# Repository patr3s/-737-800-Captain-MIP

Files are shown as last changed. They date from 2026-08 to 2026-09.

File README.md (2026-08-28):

# 737-800 Captain MIP

Modulárny 1:1 Captain-side Main Instrument Panel pre PMDG 737-800.

## Aktuálny stav

- DU bezel v2: referenčný rozmer 203,2 × 203,2 mm; aktívny otvor 169,7 × 169,7 mm.
- PFD+ND carrier v1: parametrický návrh, rozdelený na samostatný PFD a ND rám pre tlačovú plochu 260 × 260 mm.
- BenQ 18,5\" PETG cradle v1: `HOLD/DO NOT PRINT`; hlavné zaťaženie prevezme pevný oceľový VESA 100 držiak, tlačené budú iba nenosné dorazy a adaptéry.
- DU bezel v3: parametrická backlit-ready svetlá základňa, tmavá face vrstva a samostatný difúzor.
- Backlight test panel v1: technologický kupón s LED kanálom a presvietiteľnými znakmi.
- Dual-concentric knob v1: samostatné parametrické knoby; rozmery hriadeľov sú zatiaľ provisional.
- PFD/ND fascia v1: kompletná 445 × 266 mm predná maska rozdelená na tlačiteľné segmenty; čaká na CAL-003 fit-check.
- PFD/ND Pop Out alignment: fyzická 1:1 geometria prepočítaná na BenQ 1366 × 768.
- Elektronika: Arduino Mega 2560 + MobiFlight; WINCTRL MCP/EFIS.

## Štruktúra

- `CAD/` – parametrické zdrojové modely
- `Ready-to-Print/` – overené exporty určené pre 5s3a
- `Docs/` – technické poznámky, merania a montáž
- `BOM/` – zoznam dielov a stav obstarania
- `Photos/` – fotografie prototypov a montáže

## Pravidlo vydávania dielov

Súbor sa presunie do `Ready-to-Print/` až po kontrole rozmerov, úspešnom STL exporte a kontrole, že sa zmestí na 260 × 260 mm podložku. Experimentálne exporty zostávajú pri zdroji v `CAD/`.

## Najbližší mechanický krok

Dokončiť backlight test v1.1 a heat-set kalibráciu. Následne nasucho osadiť PFD/ND carrier a vybrať pevný oceľový VESA 100 držiak pre hlavné zaťaženie BenQ.

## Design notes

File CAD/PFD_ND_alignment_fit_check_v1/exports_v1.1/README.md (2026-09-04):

# CAL-003B exports

Corrective exports following the measured CAL-003 report:

- center fascia tongue stepped 4.8 mm below its feet,
- fascia seam joiner hole pitch corrected to 20 mm,
- multi-hole assembly clearance set to 3.4 mm.

The 3MF is an engineering assembly preview. Only the two STL files are print
outputs; printing instructions are in `Ready-to-Print`.

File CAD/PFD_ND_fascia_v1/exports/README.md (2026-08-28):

# PFD/ND fascia v1 – prototype exports

The folder contains base and dark-face exports for seven modular segments, optional 0,4 mm diffuser layers for the four top/bottom segments, and a rear M3 center-seam joiner.

These exports are not yet Ready-to-Print. Release depends on successful CAL-003 alignment/fit-check results.

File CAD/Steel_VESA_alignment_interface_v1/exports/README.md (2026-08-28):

# Steel VESA alignment interface v1 – PROVISIONAL

These printed parts do not carry monitor weight. The steel VESA bracket and structural MIP frame remain the primary support.

- XY plate: ±4 mm slot travel.
- Z shims: 0,5 / 1,0 / 2,0 mm.

Do not print until the exact steel VESA bracket and its frame mounting-hole pattern are selected.

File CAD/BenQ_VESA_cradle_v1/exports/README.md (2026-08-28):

# BenQ VESA cradle v1 – HOLD / DO NOT PRINT

Tieto PETG diely sa po technickej revíi nepoužijú ako hlavný dlhodobý nosník monitora. Primárne zaťaženie má niesť pevný oceľový VESA 100 × 100 mm držiak pripevnený ku konštrukcii MIP. Exporty zostávajú iba ako história návrhu.

Exporty sú geometricky skontrolované a všetky sa zmestia na Anycubic Kobra X 260 × 260 mm.

| Súbor | Počet | Rozmer dielu |
|---|---:|---:|
| `737-MIP-005_VESA-plate_v1.stl` | 1 | 170 × 170 × 7 mm |
| `737-MIP-005A_rear-wing_v1.stl` | 4 | 150 × 26 × 7 mm |
| `737-MIP-005B_depth-arm_v1.stl` | 4 | 78 × 26 × 7 mm |
| `737-MIP-005C_bottom-stabilizer_v1.stl` | 2 | 76 × 24 × 7 mm |

**Nevytlačiť ako výrobnú zostavu.**

Tlačové nastavenia a počty sú v `Docs/PRINT_BenQ_cradle_v1.md`.

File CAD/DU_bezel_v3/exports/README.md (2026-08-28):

# DU bezel v3 – exporty

| Súbor | Počet pre PFD+ND | Materiál | Stav |
|---|---:|---|---|
| `737-MIP-001_DU-bezel-light-base_v3.stl` | 2 | biely PETG | čaká na overenie servisného rastra |
| `737-MIP-001A_DU-bezel-dark-face_v3.stl` | 2 | čierny PETG | čaká na overenie servisného rastra |
| `737-MIP-001B_DU-bezel-diffuser_v3.stl` | 2 | natural/biely PETG, 0,4 mm | čaká na overenie servisného rastra |

Obrys je 203,2 × 203,2 mm a otvor 169,7 × 169,7 mm. Diely sa zmestia na Kobra X bez delenia. Zatiaľ ich nepresúvať do `Ready-to-Print`.

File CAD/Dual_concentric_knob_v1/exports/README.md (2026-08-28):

# Dual-concentric knob v1 – PROVISIONAL

Tieto STL sú iba tvarový prototyp. Neobjednávať ani netlačiť väčšiu sériu pred zmeraním konkrétneho dual-concentric enkódera.

- `737-MIP-KNB-001_lower-knob_PROVISIONAL_v1.stl`
- `737-MIP-KNB-002_upper-knob_PROVISIONAL_v1.stl`

Aktuálne bores 8,2 a 6,2 mm sú parametrické skúšobné hodnoty, nie potvrdené výrobné rozmery.

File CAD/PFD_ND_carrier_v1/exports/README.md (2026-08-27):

# Prototype exports – carrier v1

Tieto STL sú geometricky skontrolované, ale zatiaľ nie sú uvoľnené ako `Ready-to-Print`.

Pred tlačou oboch hlavných rámov treba potvrdiť, že montážne otvory fyzického alebo pôvodného DU bezel v2 majú raster 183,2 × 183,2 mm. Spojovacia lišta a horné rozhranie od tohto rastra nezávisia.

Exporty:

- `737-MIP-003_PFD-carrier_v1.stl` – ľavý PFD rám, 1 ks
- `737-MIP-004_ND-carrier_v1.stl` – pravý ND rám, 1 ks
- `737-MIP-003A_joiner-v1.stl` – nastaviteľná spojovacia lišta, 2 ks
- `737-MIP-003B_top-interface-v1.stl` – horná konzola rozhrania, 2 ks

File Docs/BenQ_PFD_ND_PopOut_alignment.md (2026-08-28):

# BenQ PFD/ND Pop Out Panel Manager alignment

## Physical source geometry

- Active LCD: 410 × 232 mm.
- BenQ resolution: 1366 × 768 px.
- PFD/ND physical opening: 169,7 × 169,7 mm.
- Center pitch: 209,8 mm.
- Visible gap: 40,1 mm.

Independent axis conversion is required because the physical pixel pitch is slightly different in X and Y:

- X: `410 / 1366 = 0,300146 mm/px`.
- Y: `232 / 768 = 0,302083 mm/px`.

## Recommended Pop Out values

The following values are relative to the top-left pixel of the BenQ desktop. If Windows places the BenQ at a non-zero desktop coordinate, add that monitor origin to `Left` and `Top`.

| Window | Left | Top | Width | Height |
|---|---:|---:|---:|---:|
| PFD | **51** | **103** | **565** | **562** |
| ND | **750** | **103** | **565** | **562** |

Unrounded calculations:

- PFD Left: 50,81 px.
- ND Left: 749,80 px.
- Top: 103,12 px.
- Width: 565,39 px.
- Height: 561,77 px.
- Pixel gap after rounding: 134 px.
- Left/right pixel margins after rounding: approximately 51 px.

These values intentionally follow the confirmed physical 1:1 geometry, not the current accidental 565 × 562 pop-out placement.

## Alignment procedure with the physical fascia

1. Configure Windows to use the BenQ at native 1366 × 768 resolution and 100 % scaling.
2. Disable overscan/scaling in the GPU and monitor menu; the desktop must fill the active LCD exactly.
3. Enter the values above for PFD and ND.
4. Install the monitor behind the fascia with the steel VESA bracket still slightly loose in X/Y.
5. Display a high-contrast calibration image or the PMDG PFD/ND pop-outs.
6. Mechanically center the active LCD behind both physical openings using the ±3 mm alignment allowance.
7. Tighten the steel bracket only after both openings show equal margins.
8. Fine-tune Pop Out values by 1–2 px only after mechanical alignment. Do not use large pixel corrections to compensate for a mechanically misplaced monitor.
9. Save the final measured values and monitor desktop origin in the project documentation.

If the physical Windows desktop is rotated, scaled, or the BenQ is not at 100 %, these coordinates must be recalculated.

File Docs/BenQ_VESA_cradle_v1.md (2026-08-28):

# BenQ VESA cradle v1 – HOLD / DO NOT PRINT

## Rozhodnutie po revízii 5s3a

Tlačený PETG cradle sa nebude používať ako hlavný dlhodobý nosný prvok. PETG sa pri trvalom statickom zaťažení môže časom dotvarovať. Hlavné zaťaženie monitora preto prevezme pevný oceľový VESA 100 × 100 mm držiak upevnený do konštrukčného rámu MIP.

Existujúce SCAD/STL zostávajú zachované ako vývojová referencia, ale majú stav `HOLD/DO NOT PRINT`. Nové tlačené diely budú iba nastaviteľné podložky, bočné dorazy a stabilizátory bez hlavnej nosnej funkcie. Tie sa navrhnú podľa geometrie vybraného oceľového držiaka a suchej montáže.

## Použité fyzické rozmery

| Parameter | Hodnota |
|---|---:|
| Monitor | 445 × 266 × 60 mm |
| Aktívna LCD plocha | 410 × 232 mm |
| Aktívna plocha odľava/zhora | 18 / 18 mm |
| VESA | 100 × 100 mm |
| Ľavá horná VESA diera odľava/zhora | približne 170 / 80 mm |

Aktuálny carrier používa medzeru 6,6 mm a celkovú šírku 445,0 mm. Bezely sú asymetricky posunuté tak, aby boli viditeľné otvory centrované na aktívnom LCD. Tento dokument ďalej opisuje pôvodný tlačený cradle iba ako archivovanú vývojovú koncepciu.

## Architektúra

- Centrálna VESA platňa 170 × 170 × 7 mm nesie hlavné zaťaženie monitora.
- Štyri zadné krídla prepájajú platňu s bočnými hĺbkovými ramenami.
- Štyri bočné ramená prenášajú zaťaženie do vonkajších okrajov PFD/ND carrieru.
- Dve spodné podpery s nastaviteľným M3 nylonovým alebo TPU dotykom iba tlmia pohyb. Nesmú nadvihovať monitor ani preberať hlavné zaťaženie.
- Monitor sa po odskrutkovaní štyroch VESA skrutiek vyberá zozadu; zadná zostava nezakrýva bočné oblasti konektorov.
- Žiadny samostatný tlačený diel neprekračuje 170 × 170 × 78 mm.

## Nastaviteľnosť

Všetky štyri VESA otvory majú zaoblený dvoj-osový obrys 10 × 10 mm s minimálnou šírkou 5,2 mm. Umožňujú približne ±2,4 mm korekciu v horizontálnom aj vertikálnom smere súčasne. Pri montáži sa použijú široké podložky, všetky skrutky sa najprv nechajú voľné a dotiahnu sa až po zarovnaní obrazu.

## Spojovací materiál

- Tlačené spoje: M3 skrutky, podložky a M3 heat-set vložky.
- VESA do monitora: 4× skrutka podľa skutočného závitu monitora, pravdepodobne M4. M3 skrutku nepoužívať len preto, že ostatné spoje sú M3.
- Maximálnu hĺbku zaskrutkovania do monitora treba overiť fyzicky. Skrutka sa nikdy nesmie dotiahnuť na doraz vo vnútri monitora.
- Odporúčané široké podložky pod všetky podlhovasté otvory.

## Prístup ku konektorom

Krídla sú umiestnené v zadnej stredovej rovine a bočné ramená mimo obrysu monitora. VGA a napájací konektor musia byť pri prvej suchej montáži overené so zapojenými káblami. Kábel potrebuje voľný polomer ohybu; ak konkrétny konektor koliduje, príslušné krídlo sa presunie v slote, nie kábel násilne ohne.

## Poradie montáže

1. Zmontovať PFD a ND carrier so stredovou medzerou 6,6 mm, zatiaľ bez monitora.
2. Osadiť bočné hĺbkové ramená, ale M3 skrutky nechať mierne povolené.
3. Pripojiť štyri zadné krídla k VESA platni.
4. Priložiť zostavu k monitoru a overiť závit aj bezpečnú dĺžku VESA skrutiek.
5. Zavesiť monitor cez VESA, zapojiť VGA aj napájanie a skontrolovať prístup.
6. Zarovnať aktívnu plochu za DU otvormi a postupne dotiahnuť VESA a M3 spoje.
7. Spodné stabilizátory nastaviť iba na ľahký dotyk s krytom monitora.

## Pred tlačou celej zostavy

- Vytlačiť M3 kalibračný diel a preniesť výsledný priemer heat-set kapsy do parametra `m3_insert`.
- Fyzicky overiť, že VESA závit je M4 a zistiť bezpečnú dĺžku skrutky.
- Overiť raster servisných otvorov DU bezel v2.
- Urobiť suchý CAD/ručný test polohy VGA a napájacieho konektora podľa fotografie zadnej strany.

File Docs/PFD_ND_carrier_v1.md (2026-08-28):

# PFD + ND carrier v1

## Účel

Carrier v1 je pevná, servisovateľná základňa pre dva samostatné DU bezely. Nie je to držiak monitora. BenQ bude mať vlastnú zadnú kolísku, doplnenú po fyzickom meraní.

Fyzické rozmery BenQ sú už zapracované. Nominálna stredová medzera medzi carrier rámami je **6,6 mm**, takže zostava má šírku presne **445,0 mm**. Bezely sú v carrier rámoch asymetricky posunuté smerom k stredu: ľavý +8,5 mm a pravý −7,5 mm. Tým je fyzická medzera bezelov tiež 6,6 mm a viditeľné otvory sú centrované na aktívnom LCD.

## Konštrukcia

- Dva samostatné rámy PFD a ND, každý 219,2 × 219,2 × 5 mm.
- Každý hlavný diel sa zmestí na tlačovú plochu 260 × 260 mm.
- Otvor rámu je 170,7 × 170,7 mm (169,7 mm aktívny otvor + 1,0 mm montážna vôľa).
- Bezel sa upevňuje štyrmi M3 skrutkami; nominálny servisný raster je 183,2 × 183,2 mm.
- Dve samostatné spojovacie lišty so slotmi ponechávajú rozstup PFD/ND nastaviteľný.
- Horné sloty tvoria rozhranie pre budúci nosník EFIS/MCP.
- ND rám má na pravom okraji tri sloty pre napojenie center MIP.
- Vonkajšie okraje majú dvojicu slotov pre bočné hĺbkové ramená BenQ cradle.

## Dôležitá otvorená položka

Raster 183,2 × 183,2 mm bol rekonštruovaný z deklarovaných servisných bodov bezel v2 (10 mm od okrajov). Pred tlačou celej zostavy treba porovnať zdrojový alebo fyzický bezel v2. Ak sa líši, upraví sa parameter `bezel_hole_edge`.

## Odporúčaná skúšobná tlač

- Materiál: PETG pre finálny nosný diel; PLA je vhodné na rozmerový prototyp.
- Vrstva: 0,20 mm.
- Steny: 4.
- Horné/spodné vrstvy: 5.
- Výplň: 20–25 % gyroid.
- Orientácia: naplocho, zadnou stranou na podložke.
- Podpery: bez podpier.
- Kompenzácia elephant foot: podľa kalibrácie tlačiarne.

## Spojovací materiál pre carrier

- 8× M3 skrutka pre bezely (dĺžka podľa reálnej hĺbky vložky).
- 4× M3 skrutka + 4× matica alebo heat-set vložka pre dve spojovacie lišty.
- 4× M3 skrutka pre dve horné konzoly rozhrania.
- 3× M3 skrutka pre pravé rozhranie na center MIP.

## Stav verifikácie

- [x] Parametrický zdroj vytvorený.
- [x] Maximálny obrys hlavného dielu pod 260 × 260 mm.
- [x] STL exportovaný; OpenSCAD CGAL kontrola: `Simple: yes`.
- [x] Obrysy exportov skontrolované: 219,2 × 219,2 × 5 mm (PFD/ND), 92 × 18 × 5 mm (spojka), 80 × 22 × 5 mm (horné rozhranie).
- [ ] Overený raster otvorov proti bezel v2.
- [ ] Skúšobne vytlačené.
- [ ] Rozstup PFD/ND uzamknutý po fyzickom CAL-003 fit-check teste.
- [x] Nominálna medzera rámov nastavená na 6,6 mm podľa 445 mm obrysu monitora.

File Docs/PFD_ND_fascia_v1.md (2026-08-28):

# PFD/ND fascia v1

## Purpose

The fascia covers the full 445 × 266 mm monitor envelope and masks every LCD area outside the two confirmed 169,7 mm DU openings. Two 203,2 mm bezel assemblies install into 203,6 mm fascia cutouts, providing 0,2 mm nominal clearance per edge.

## Printable segmentation

The fascia is divided into seven base/face segments:

- top-left and top-right rails,
- bottom-left and bottom-right rails,
- left outer rail,
- center rail,
- right outer rail.

Top and bottom center seams use rear 70 × 16 × 3 mm M3 joiner plates. The narrow center rail is captured by the two bezels and the top/bottom rails; it is a mask, not a primary structural member. Carrier frames behind the fascia provide the main printed-module stiffness.

No fascia segment exceeds 222,5 × 203,6 mm, so every part fits the 260 × 260 mm Kobra X bed.

## Layer philosophy

- Light base: 3,2 mm white/light PETG.
- Dark face: 1,0 mm black PETG.
- Optional diffuser under future illuminated top/bottom legends: 0,4 mm white/natural PETG.
- Rear cable routes are reserved for a separate panel-dimmer circuit.
- The DU bezel v3 carries its own 5,6 × 2,0 mm channel for 5 mm COB lighting.

No unverified Boeing legend positions are engraved in v1. The screenshot is used only as a visual reference; future legends remain parameterized until reliable 1:1 dimensions are available.

## Service

The fascia and bezels are removed from the front with M3 screws. The monitor remains independently supported by the future fixed steel VESA bracket and is removed from the rear. Fascia/carrier parts only establish alignment and light stabilization; they do not carry monitor weight.

## Release status

CAD/STL are prototype exports. They remain outside `Ready-to-Print` until the center alignment fit-check confirms:

- 6,6 mm physical bezel gap,
- carrier-to-bezel offset,
- fascia cutout clearance,
- center mask fit,
- M3 seam registration.

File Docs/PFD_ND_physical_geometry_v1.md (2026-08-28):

# PFD + ND physical geometry v1

## Confirmed inputs

- BenQ body: 445 × 266 × 60 mm.
- Active LCD: 410 × 232 mm.
- Active LCD offset: 18 mm left and 18 mm top; derived right border is 17 mm and bottom border 16 mm.
- DU visible opening: 169,7 × 169,7 mm.
- DU bezel: 203,2 × 203,2 mm.

## Final nominal arrangement

The carrier pair is 445,0 mm wide: `219,2 + 6,6 + 219,2`. The physical bezel gap is also 6,6 mm because each bezel is shifted toward the center of its asymmetric carrier. The complete visible pair is centered on the active LCD, not on the monitor plastic.

| Quantity | Value |
|---|---:|
| Physical bezel gap | 6,6 mm |
| PFD-center to ND-center pitch | 209,8 mm |
| Gap between visible DU openings | 40,1 mm |
| Total visible pair width | 379,5 mm |
| Active LCD margin left/right | 15,25 / 15,25 mm |
| Active LCD margin top/bottom | 31,15 / 31,15 mm |

Coordinates below use the active LCD top-left as `(0,0)`:

| Opening | Left | Top | Width | Height | Center X | Center Y |
|---|---:|---:|---:|---:|---:|---:|
| PFD | 15,25 | 31,15 | 169,7 | 169,7 | 100,10 | 116,00 |
| ND | 225,05 | 31,15 | 169,7 | 169,7 | 309,90 | 116,00 |

Coordinates relative to the complete 445 × 266 mm monitor body:

| Opening | Left | Top | Center X | Center Y |
|---|---:|---:|---:|---:|
| PFD | 33,25 | 49,15 | 118,10 | 134,00 |
| ND | 243,05 | 49,15 | 327,90 | 134,00 |

The physical bezel outer edges are at X 16,5–219,7 mm and 226,3–429,5 mm. This leaves 16,5 mm at the monitor left and 15,5 mm at the right, matching the 0,5 mm active-area offset relative to the monitor-body center.

## Change from the previous carrier

The previous 7 mm carrier gap with centered bezels produced a physical bezel gap of approximately 23 mm because each 219,2 mm carrier added an 8 mm inner margin. In v1 final geometry:

- carrier gap changes from 7,0 to 6,6 mm,
- the left bezel shifts +8,5 mm toward the center,
- the right bezel shifts −7,5 mm toward the center,
- physical bezel gap becomes 6,6 mm,
- visible opening gap becomes 40,1 mm.

The 6,6 mm physical gap is a project interface derived from confirmed monitor and bezel dimensions. It remains parameterized and should be verified with the low-cost center fit-check before large prints.

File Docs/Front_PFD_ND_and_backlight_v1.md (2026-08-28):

# Viditeľná PFD/ND časť a backlight v1

## Rozmerová politika

Referenčný PMDG screenshot sa používa iba na identifikáciu vizuálneho usporiadania a typov ovládačov. Rozmery odvodené iba z pixelov sa nepoužívajú ako výrobné rozmery.

Potvrdené rozmery DU sú 203,2 × 203,2 mm a otvor 169,7 × 169,7 mm. Nový bezel v3 používa rovnaký nominálny servisný raster 183,2 × 183,2 mm ako carrier v1. Raster treba pred veľkou tlačou overiť vytlačením rohového fit-check dielu alebo fyzickým meraním.

## DU bezel v3

Bezel je rozdelený na:

- svetlú nosnú základňu 3,2 mm,
- tmavú prednú vrstvu 1,2 mm,
- samostatný 0,4 mm difúzny prstenec,
- spredu otvorený LED kanál široký 5,6 mm a hlboký 2,0 mm pre 5 mm COB pásik,
- štyri alternatívne vývody kabeláže,
- štyri servisné M3 otvory.

Rovnaký model sa použije pre PFD aj ND. Čierna predná vrstva sa môže tlačiť priamo alebo nastriekať; svetlá základňa a difúzor majú zostať svetlé/priesvitné v miestach presvietenia.

## Dual-concentric ovládače

Červeným označené ovládače na referencii sú dvojité koncentrické prvky. Panelový otvor aj oba knob kryty sú parametrické. Aktuálne skúšobné hodnoty 10,2 mm panelový otvor, 8,2 mm spodný shaft a 6,2 mm horný shaft sú **provisional** a nesmú sa použiť ako finálny fit bez zmerania konkrétneho enkódera.

Knoby sú oddelené diely:

- spodný knob: 28 × 10 mm,
- horný knob: 17 × 14 mm,
- radiálny pilot pre M3 zaisťovaciu skrutku.

## Backlight testovací panel

Opravená revízia 1.1 panelu 120 × 62 mm testuje:

- dvojmateriálovú skladbu svetlá základňa/tmavá maska,
- presvietiteľné texty a symbol,
- 0,4 mm difúzor medzi LED a čiernou face vrstvou,
- 2,0 mm spredu otvorený LED kanál a bočný vývod,
- otvor pre budúci dual-concentric encoder,
- servisné M3 upevnenie.

Použiť dva rovné približne 90 mm úseky 12 V bieleho COB pásika širokého 5 mm. Čierna face vrstva používa stencil písmo, takže stredy písmen nie sú samostatné neprintovateľné ostrovčeky. Samostatný dimmer okruh má používať vlastné dva vodiče a spoločný bod napájania až v elektronickej rozvodnici.

## V1 výnimky

- Analógový flap indicator môže zostať nefunkčný placeholder alebo byť vynechaný.
- Zeleno označený manuálny ukazovateľ sa do v1 nezahŕňa.

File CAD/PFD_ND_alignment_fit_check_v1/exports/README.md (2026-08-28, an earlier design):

# PFD/ND alignment fit-check v1

Geometrically identical verified STL files are released in `Ready-to-Print/PFD-ND-Alignment-Fit-Check-v1` with print and measurement instructions.

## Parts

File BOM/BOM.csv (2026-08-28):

Category | Item | Specification | Quantity | Status | Notes
Electronics | Arduino Mega 2560 | Rev3 | 1 | ordered | MobiFlight controller
Controls | Rotary encoder | EC11 with D-shaft and push switch | 5 | ordered | Prototype stock
Controls | Toggle switch | MTS-103 3-position 3-pin | 5 | ordered | Prototype stock
Avionics | WINCTRL MCP/EFIS | 737NG compatible | 1 | set | Upper interface reserved
Display | BenQ monitor | 18.5 inch 445x266x60 mm VESA 100x100 | 1 | measured | Active area 410x232 offset 18x18 mm
Hardware | Heat-set insert | M3 for printed plastic | TBD | to purchase | Confirm outer diameter before pocket freeze
Hardware | Screw | M3 assorted lengths | TBD | to purchase | Final lengths after stack-up test
Printed | PFD carrier frame | v1 PETG | 1 | design | 219.2 x 219.2 x 5 mm
Printed | ND carrier frame | v1 PETG | 1 | design | 219.2 x 219.2 x 5 mm
Printed | Carrier joiner bar | v1 PETG | 2 | design | Slotted adjustment
Printed | Upper EFIS/MCP interface | v1 PETG | 2 | design | One provisional bracket per DU
Printed | M3 calibration coupon | v1 PETG | 1 | ready to print | Print before carrier frames
Printed | BenQ VESA center plate | v1 PETG | 1 | HOLD DO NOT PRINT | Superseded as primary support due to PETG creep
Printed | BenQ rear wing | v1 PETG | 4 | HOLD DO NOT PRINT | Superseded by steel VESA support concept
Printed | BenQ side depth arm | v1 PETG | 4 | HOLD DO NOT PRINT | Superseded by steel VESA support concept
Printed | BenQ bottom stabilizer | v1 PETG | 2 | redesign pending | May return as non-load-bearing alignment stop
Hardware | Fixed steel VESA bracket | 100x100 mm low-profile | 1 | to select | Primary monitor support attached to MIP structure
Printed | DU bezel light base | v3 light or white PETG | 2 | design | Backlit-ready; verify 183.2 mm service-hole pitch
Printed | DU bezel dark face | v3 black PETG | 2 | design | Visible PFD and ND face layer
Printed | DU bezel diffuser ring | v3 natural or white PETG | 2 | design | 0.4 mm backlight diffuser
Printed | Backlight test base | v1 white PETG | 1 | ready to print | Technology coupon only
Printed | Backlight test dark face | v1 black PETG | 1 | ready to print | Technology coupon only
Printed | Backlight test diffuser | v1.1 natural or white PETG 0.4 mm | 1 | ready to print | Technology coupon only
Printed | Dual concentric lower knob | v1 black PETG | TBD | provisional | Requires encoder shaft measurement
Printed | Dual concentric upper knob | v1 black PETG | TBD | provisional | Requires encoder shaft measurement
Printed | PFD/ND fascia light base segments | v1 white PETG | 7 | prototype | Release after CAL-003 fit-check
Printed | PFD/ND fascia dark face segments | v1 black PETG | 7 | prototype | Release after CAL-003 fit-check
Printed | PFD/ND fascia diffuser segments | v1 natural or white PETG 0.4 mm | 4 | prototype | Top/bottom rails only
Printed | PFD/ND fascia center seam joiner | v1 PETG | 2 | prototype | M3 rear joiner for top and bottom seams
Printed | PFD/ND alignment fit-check | CAL-003 PETG | 1 set | ready to print | 9 small parts; no heat-set inserts required
Printed | Steel VESA XY alignment plate | v1 PETG | TBD | provisional | Non-load-bearing; exact steel bracket pending
Printed | Steel VESA Z shim set | 0.5/1.0/2.0 mm PETG | TBD | provisional | Non-load-bearing depth adjustment

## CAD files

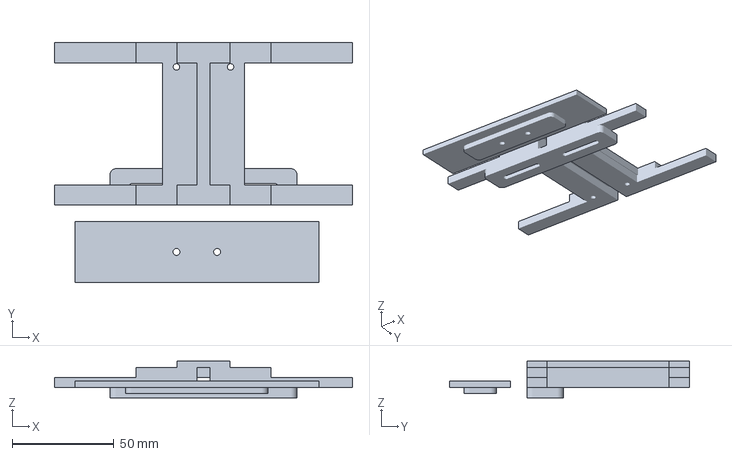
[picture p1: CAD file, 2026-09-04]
CAD/PFD_ND_alignment_fit_check_v1/exports_v1.1/737-MIP-CAL-003B_assembly-preview_v1.1.3mf
146.6 x 118.0 x 18.0 mm

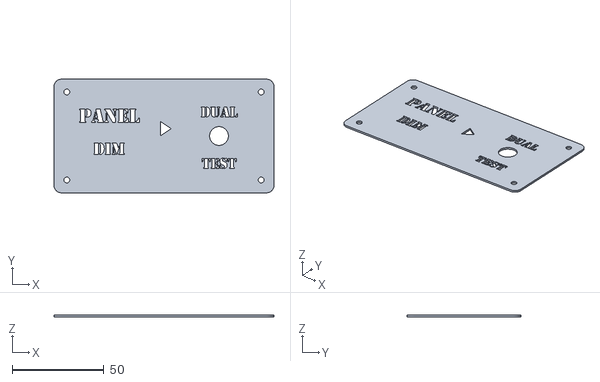
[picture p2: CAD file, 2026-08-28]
CAD/Backlight_test_panel_v1/exports/737-MIP-CAL-002A_backlight-face_v1.1.stl
120.0 x 62.0 x 1.00

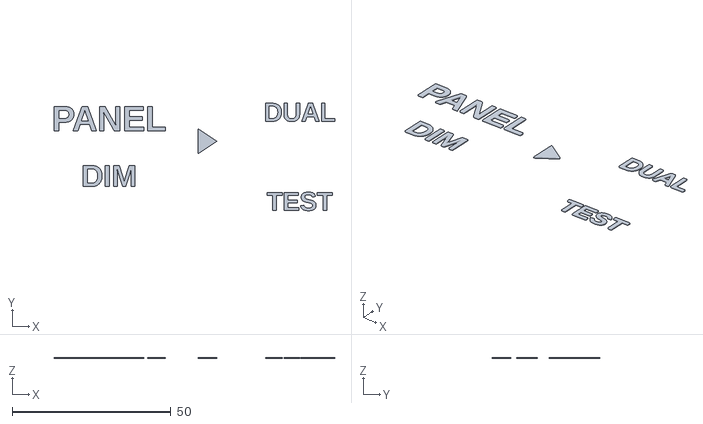
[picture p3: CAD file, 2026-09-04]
CAD/Backlight_test_panel_v1/exports_multicolor_v1/737-MIP-CAL-004_legends-B-0.4mm.stl
88.4 x 33.9 x 0.4

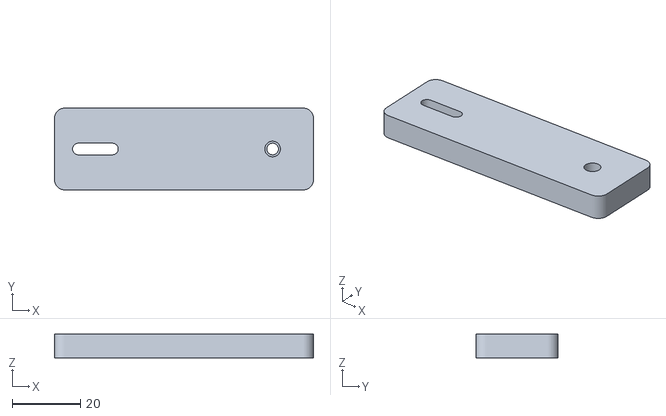
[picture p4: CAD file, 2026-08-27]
CAD/BenQ_VESA_cradle_v1/exports/737-MIP-005C_bottom-stabilizer_v1.stl
76.0 x 24.0 x 7.00

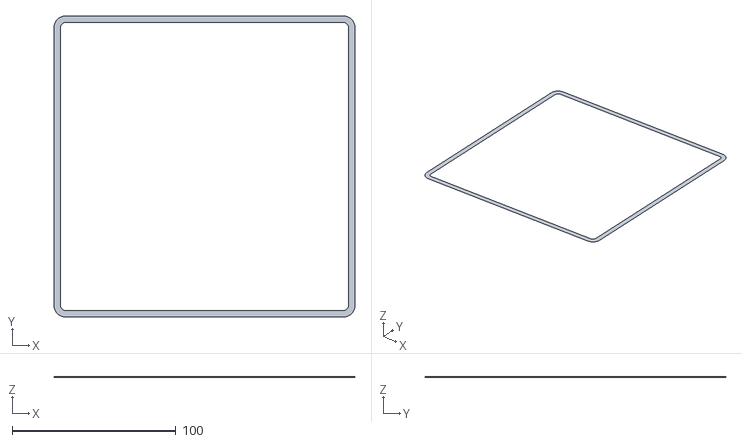
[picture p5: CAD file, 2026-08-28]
CAD/DU_bezel_v3/exports/737-MIP-001B_DU-bezel-diffuser_v3.stl
183.7 x 183.7 x 0.4

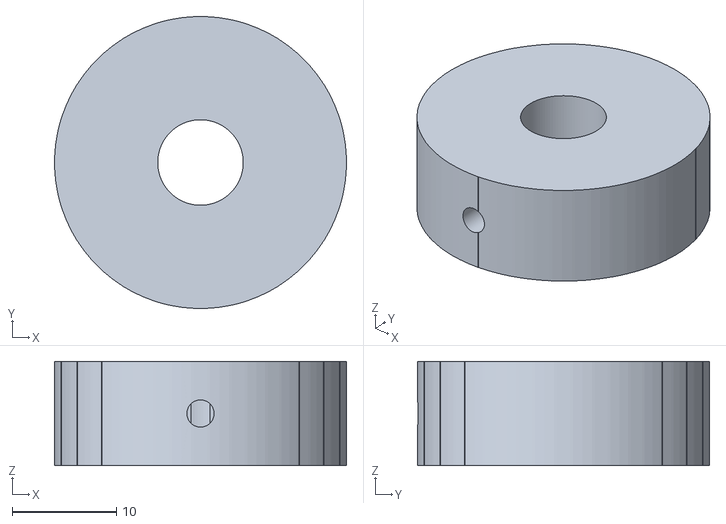
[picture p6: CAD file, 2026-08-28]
CAD/Dual_concentric_knob_v1/exports/737-MIP-KNB-001_lower-knob_PROVISIONAL_v1.stl
28.0 x 28.0 x 10.0

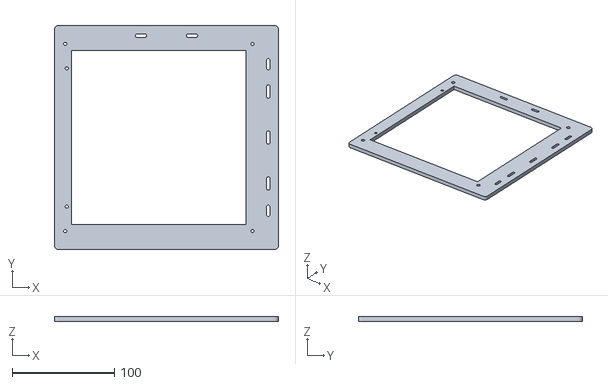
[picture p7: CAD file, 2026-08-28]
CAD/PFD_ND_carrier_v1/exports/737-MIP-004_ND-carrier_v1.stl
219.2 x 219.2 x 5.00

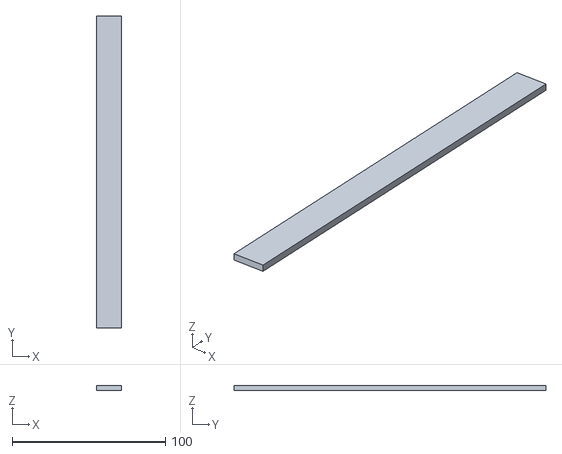
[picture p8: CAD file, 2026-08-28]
CAD/PFD_ND_fascia_v1/exports/737-MIP-006_left_rail_base_v1.stl
16.3 x 203.6 x 3.20

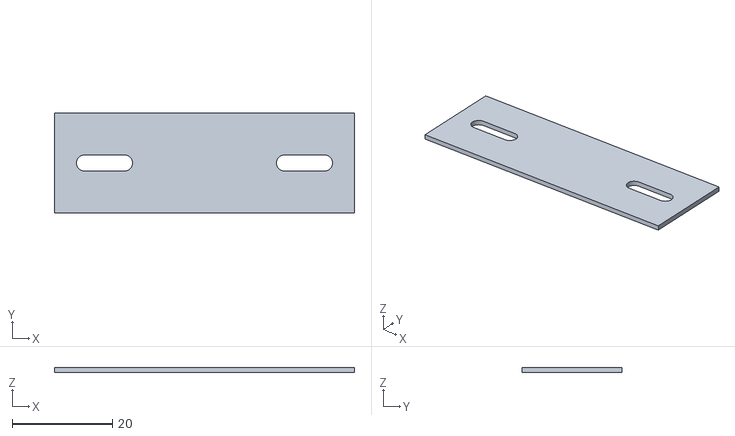
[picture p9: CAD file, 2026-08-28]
CAD/Steel_VESA_alignment_interface_v1/exports/737-MIP-007_shim_10_PROVISIONAL_v1.stl
60.0 x 20.0 x 1.00

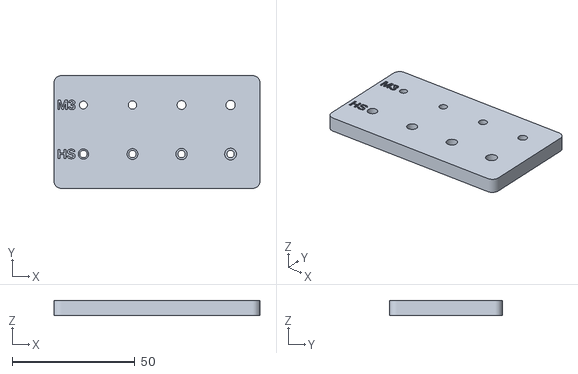
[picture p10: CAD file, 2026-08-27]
Ready-to-Print/737-MIP-CAL-001_M3-calibration-coupon_v1.stl
84.0 x 46.0 x 6.00

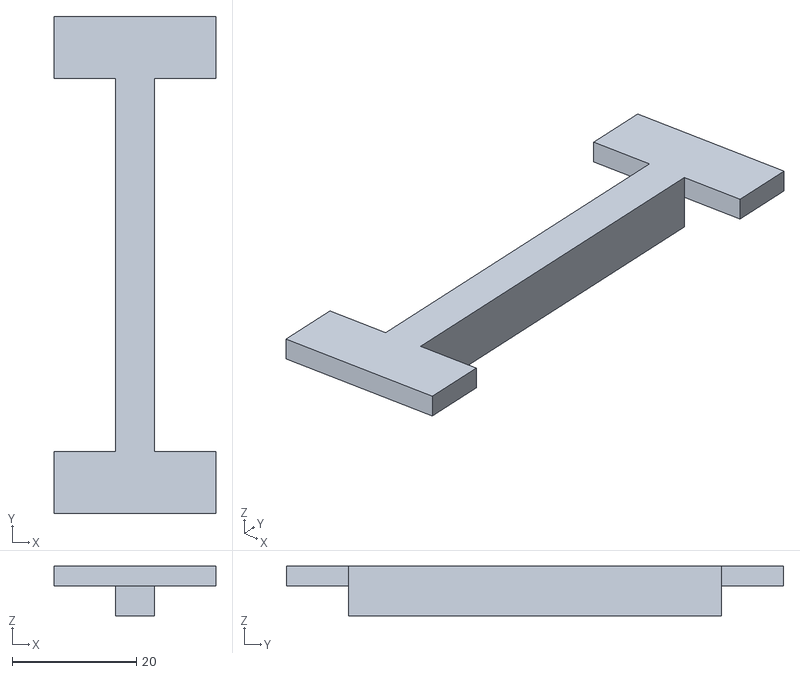
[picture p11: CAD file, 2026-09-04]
Ready-to-Print/PFD-ND-Alignment-Correction-CAL-003B/737-MIP-CAL-003B_fascia-center_v1.1.stl
26.0 x 80.0 x 8.00

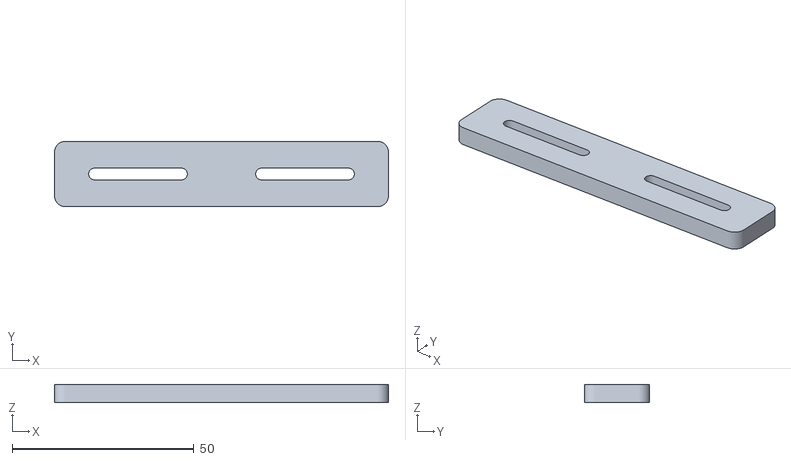
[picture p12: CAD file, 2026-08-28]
Ready-to-Print/PFD-ND-Alignment-Fit-Check-v1/737-MIP-CAL-003_carrier_joiner_v1.stl
92.0 x 18.0 x 5.00

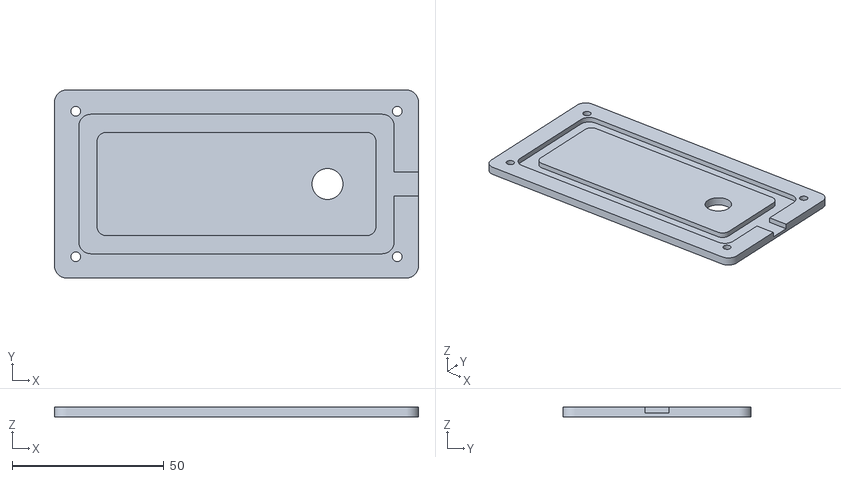
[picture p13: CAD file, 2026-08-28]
CAD/Backlight_test_panel_v1/exports/737-MIP-CAL-002_backlight-base_v1.1.stl
120.0 x 62.0 x 3.20

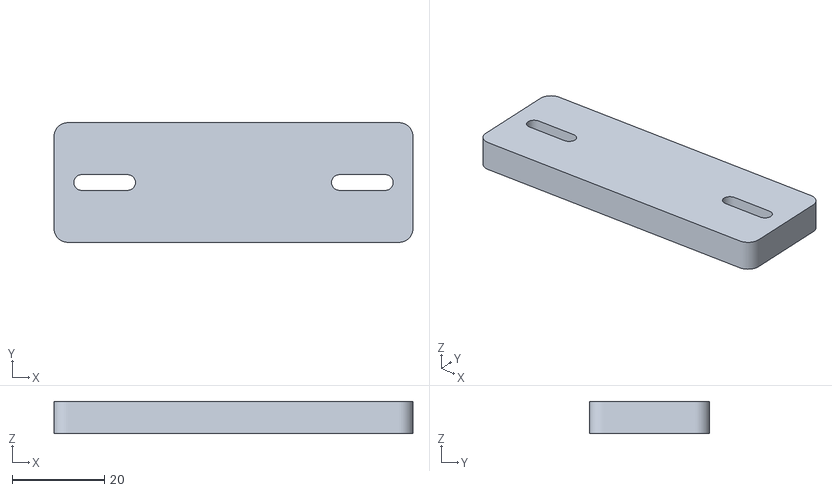
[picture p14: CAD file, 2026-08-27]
CAD/BenQ_VESA_cradle_v1/exports/737-MIP-005B_depth-arm_v1.stl
78.0 x 26.0 x 7.00

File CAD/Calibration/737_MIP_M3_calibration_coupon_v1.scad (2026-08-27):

/*
  737-800 Captain MIP – M3 print calibration coupon v1
  Units: mm

  Row A: heat-set insert pockets 4.2 / 4.4 / 4.6 / 4.8 mm
  Row B: M3 clearance holes 3.2 / 3.4 / 3.6 / 3.8 mm
*/

$fn = 64;

coupon_x = 84;
coupon_y = 46;
coupon_z = 6;
corner_r = 3;
test_x = [12, 32, 52, 72];
heatset_d = [4.2, 4.4, 4.6, 4.8];
clearance_d = [3.2, 3.4, 3.6, 3.8];
heatset_depth = 4.2;
pilot_d = 3.0;

module rounded_plate() {
    hull() {
        for (x = [corner_r, coupon_x-corner_r])
            for (y = [corner_r, coupon_y-corner_r])
                translate([x,y,0]) cylinder(h=coupon_z, r=corner_r);
    }
}

module engraved_label(label, x, y) {
    translate([x, y, coupon_z-0.5])
        linear_extrude(0.6)
            text(label, size=4, halign="center", valign="center",
                 font="Liberation Sans:style=Bold");
}

difference() {
    rounded_plate();

    // Heat-set pockets with a smaller pilot hole continuing through the base.
    for (i = [0:3]) {
        translate([test_x[i], 14, coupon_z-heatset_depth])
            cylinder(h=heatset_depth+0.1, d=heatset_d[i]);
        translate([test_x[i], 14, -0.1])
            cylinder(h=coupon_z-heatset_depth+0.2, d=pilot_d);
    }

    // Through-holes for checking printed M3 running clearance.
    for (i = [0:3])
        translate([test_x[i], 34, -0.1])
            cylinder(h=coupon_z+0.2, d=clearance_d[i]);

    // Recessed row markers.
    engraved_label("HS", 5, 14);
    engraved_label("M3", 5, 34);
}

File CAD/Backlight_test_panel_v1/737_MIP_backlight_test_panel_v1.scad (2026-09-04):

/*
  Backlight multicolor A/B technology coupon, CAL-004
  Tests: light base, multicolor dark face + translucent legends, LED cavity,
  rear service access and dual-concentric encoder panel opening.
*/

$fn = 64;
part = "assembly";

panel_w = 120;
panel_h = 62;
corner_r = 4;
base_t = 3.2;
face_t = 1.0;
legend_b_t = 0.4; // empirically verified by 5s3a: 2 layers at 0.20 mm
encoder_hole = 10.2; // provisional until the selected encoder is measured
m3_clearance = 3.2; // calibrated on Anycubic Kobra X, Anycubic PETG, flow 0.96
led_channel_depth = 2.0;

module rounded_rect_2d(size,r) {
    hull()
        for(x=[r,size[0]-r]) for(y=[r,size[1]-r])
            translate([x,y]) circle(r=r);
}

module mounting_holes(h) {
    for(x=[7,panel_w-7]) for(y=[7,panel_h-7])
        translate([x,y,-0.1]) cylinder(h=h+0.2,d=m3_clearance);
}

module labels_2d() {
    // Normal bold font: counters are retained by the separately printed legends.
    translate([30,42]) text("PANEL",size=8,halign="center",valign="center",
                            font="Liberation Sans:style=Bold");
    translate([30,24]) text("DIM",size=7,halign="center",valign="center",
                            font="Liberation Sans:style=Bold");
    translate([90,44]) text("DUAL",size=6,halign="center",valign="center",
                            font="Liberation Sans:style=Bold");
    translate([90,16]) text("TEST",size=6,halign="center",valign="center",
                            font="Liberation Sans:style=Bold");
    translate([58,31]) polygon(points=[[0,0],[6,4],[0,8]]);
}

module light_base() {
    difference() {
        linear_extrude(base_t) rounded_rect_2d([panel_w,panel_h],corner_r);
        mounting_holes(base_t);
        translate([90,31,-0.1]) cylinder(h=base_t+0.2,d=encoder_hole);

        // Front-open light cavity. Two straight 5 mm COB strips sit on its
        // long edges; the multicolor white legends provide final diffusion.
        translate([8,8,base_t-led_channel_depth])
            linear_extrude(led_channel_depth+0.1)
                difference() {
                    rounded_rect_2d([104,46],4);
                    // Retain a support boss around the provisional encoder.
                    translate([82,23]) circle(d=18);
                }
        translate([108,27,base_t-led_channel_depth])
            cube([12,8,led_channel_depth+0.1]);
    }
}

module face_black() {
    difference() {
        linear_extrude(face_t) rounded_rect_2d([panel_w,panel_h],corner_r);
        mounting_holes(face_t);
        translate([90,31,-0.1]) cylinder(h=face_t+0.2,d=encoder_hole);
        linear_extrude(face_t+0.2) labels_2d();
    }
}

module face_legends(h) {
    linear_extrude(h) labels_2d();
}

module assembly_preview() {
    color("ivory") light_base();
    color([0.12,0.12,0.12]) translate([0,0,base_t]) face_black();
    color([1,0.8,0.25,0.9]) translate([0,0,base_t]) face_legends(legend_b_t);
}

if(part=="base") light_base();
else if(part=="face_black") face_black();
else if(part=="legends_a") face_legends(face_t);
else if(part=="legends_b") face_legends(legend_b_t);
else assembly_preview();

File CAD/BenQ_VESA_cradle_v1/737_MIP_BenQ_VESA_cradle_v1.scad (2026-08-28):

/*
  737-800 Captain MIP – BenQ 18.5 inch VESA cradle v1
  Units: mm

  Measured monitor:
    body 445 x 266 x 60
    active area 410 x 232, offset 18 left / 18 top
    VESA 100 x 100
    top-left VESA hole approx. 170 left / 80 top

  Printed joints use M3 + heat-set inserts. The four screws entering the
  monitor must match its native VESA thread (normally M4; verify physically).
*/

$fn = 48;
part = "assembly";

monitor_w = 445;
monitor_h = 266;
monitor_d = 60;
active_w = 410;
active_h = 232;
active_left = 18;
active_top = 18;

carrier_w = 445.4;
carrier_h = 219.2;
carrier_t = 5;
monitor_x = (carrier_w-monitor_w)/2;
monitor_y = 6.25; // aligns active top with the DU opening datum
monitor_front_z = 9;

vesa_pitch = 100;
vesa_tl_x = 170;
vesa_tl_y = 80;
vesa_center_x = monitor_x + vesa_tl_x + vesa_pitch/2;
vesa_center_y = monitor_y + vesa_tl_y + vesa_pitch/2;
vesa_plane_z = monitor_front_z + monitor_d;

plate_w = 170;
plate_h = 170;
plate_t = 7;
plate_corner = 5;
vesa_slot_len = 10; // ±2.4 mm around a 5.2 mm M4 clearance width
vesa_clearance = 5.2;

m3_clearance = 3.2; // calibrated by 5s3a; printed cradle remains on HOLD
m3_insert = 4.6;
m3_slot_len = 10;

wing_len = 150;
wing_w = 26;
wing_t = 7;
depth_arm_len = 78;
depth_arm_w = 26;
depth_arm_t = 7;
side_offset = 12;

stabilizer_len = 76;
stabilizer_w = 24;
stabilizer_t = 7;
pad_hole_d = 3.4;

module rounded_plate(size, r=3) {
    hull() {
        for (x = [r, size[0]-r])
            for (y = [r, size[1]-r])
                translate([x,y,0]) cylinder(h=size[2], r=r);
    }
}

module slot_x(length, diameter, height) {
    hull() {
        translate([-length/2,0,0]) cylinder(h=height,d=diameter);
        translate([ length/2,0,0]) cylinder(h=height,d=diameter);
    }
}

module slot_y(length, diameter, height) {
    rotate([0,0,90]) slot_x(length,diameter,height);
}

module adjust_hole_2d(travel, diameter, height) {
    delta = (travel-diameter)/2;
    hull()
        for (x=[-delta,delta]) for (y=[-delta,delta])
            translate([x,y,0]) cylinder(h=height,d=diameter);
}

module vesa_plate() {
    difference() {
        rounded_plate([plate_w,plate_h,plate_t],plate_corner);

        // Rounded-square openings compensate the approximate C and D
        // dimensions simultaneously (about +/-2.4 mm in both axes).
        for (sx=[-1,1]) for (sy=[-1,1])
            translate([plate_w/2+sx*vesa_pitch/2,
                       plate_h/2+sy*vesa_pitch/2,-0.1])
                adjust_hole_2d(vesa_slot_len,vesa_clearance,plate_t+0.2);

        // M3 wing interfaces: two per side, slotted vertically.
        for (x=[10,plate_w-10]) for (y=[32,plate_h-32])
            translate([x,y,-0.1]) slot_y(m3_slot_len,m3_clearance,plate_t+0.2);

        // Cable/service opening and weight reduction.
        translate([plate_w/2-29,plate_h/2-29,-0.1])
            rounded_plate([58,58,plate_t+0.2],6);
    }
}

module rear_wing() {
    difference() {
        rounded_plate([wing_len,wing_w,wing_t],3);
        for (x=[12,wing_len-12])
            translate([x,wing_w/2,-0.1])
                slot_x(m3_slot_len,m3_clearance,wing_t+0.2);
    }
}

module depth_arm() {
    // Printed flat. Two holes attach to carrier/rear wing with M3 fasteners.
    difference() {
        rounded_plate([depth_arm_len,depth_arm_w,depth_arm_t],3);
        for (x=[11,depth_arm_len-11])
            translate([x,depth_arm_w/2,-0.1])
                slot_x(m3_slot_len,m3_clearance,depth_arm_t+0.2);
    }
}

module bottom_stabilizer() {
    // Carries no main load. An M3 nylon-tip screw or TPU pad lightly contacts
    // the monitor casing and prevents fore/aft vibration.
    difference() {
        rounded_plate([stabilizer_len,stabilizer_w,stabilizer_t],3);
        translate([12,stabilizer_w/2,-0.1])
            slot_x(m3_slot_len,m3_clearance,stabilizer_t+0.2);
        translate([stabilizer_len-12,stabilizer_w/2,-0.1])
            cylinder(h=stabilizer_t+0.2,d=pad_hole_d);
        translate([stabilizer_len-12,stabilizer_w/2,stabilizer_t-4.2])
            cylinder(h=4.3,d=m3_insert);
    }
}

module assembly_preview() {
    // Monitor envelope (transparent); connector side remains unobstructed.
    color([0.12,0.12,0.12,0.45])
        translate([monitor_x,monitor_y,monitor_front_z])
            cube([monitor_w,monitor_h,monitor_d]);

    // Central VESA plate behind monitor.
    color("orange")
        translate([vesa_center_x-plate_w/2,vesa_center_y-plate_h/2,vesa_plane_z])
            vesa_plate();

    // Four rear wings. They terminate outside the monitor sides and attach to
    // the depth arms; all are separate printable pieces.
    for (y=[vesa_center_y-50,vesa_center_y+50]) {
        color("goldenrod")
            translate([-side_offset,y-wing_w/2,vesa_plane_z]) rear_wing();
        color("goldenrod")
            translate([carrier_w+side_offset-wing_len,y-wing_w/2,vesa_plane_z]) rear_wing();
    }

    // Side depth arms shown upright, clear of the monitor side walls.
    for (x=[-side_offset,carrier_w+side_offset-depth_arm_w])
        for (y=[38,carrier_h-38])
            color("steelblue")
                translate([x,y-depth_arm_w/2,0])
                    rotate([0,-90,0]) depth_arm();

    // Two lower stabilizers; contact force is adjusted with M3 screws/pads.
    for (x=[28,carrier_w-28-stabilizer_w])
        color("darkorange")
            translate([x,carrier_h+36,monitor_front_z])
                rotate([0,90,0]) bottom_stabilizer();
}

if (part=="vesa_plate") vesa_plate();
else if (part=="rear_wing") rear_wing();
else if (part=="depth_arm") depth_arm();
else if (part=="bottom_stabilizer") bottom_stabilizer();
else assembly_preview();

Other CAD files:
Ready-to-Print/Backlight-Multicolor-AB-CAL-004/737-MIP-CAL-004_face-black.stl
CAD/Backlight_test_panel_v1/exports_multicolor_v1/737-MIP-CAL-004_backlight-base.stl
CAD/DU_bezel_v3/exports/737-MIP-001_DU-bezel-light-base_v3.stl
CAD/DU_bezel_v3/737_MIP_DU_bezel_v3.scad
CAD/Backlight_test_panel_v1/exports/737-MIP-CAL-002B_backlight-diffuser_v1.1.stl
CAD/Backlight_test_panel_v1/exports_multicolor_v1/737-MIP-CAL-004_face-black.stl
CAD/Backlight_test_panel_v1/exports_multicolor_v1/737-MIP-CAL-004_legends-A-1.0mm.stl
CAD/Backlight_test_panel_v1/obsolete_v1/737-MIP-CAL-002A_backlight-face_v1.stl
CAD/Backlight_test_panel_v1/obsolete_v1/737-MIP-CAL-002B_backlight-diffuser_v1.stl
CAD/Backlight_test_panel_v1/obsolete_v1/737-MIP-CAL-002_backlight-base_v1.stl
CAD/BenQ_VESA_cradle_v1/exports/737-MIP-005A_rear-wing_v1.stl
CAD/BenQ_VESA_cradle_v1/exports/737-MIP-005_VESA-plate_v1.stl
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

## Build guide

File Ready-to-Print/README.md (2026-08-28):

# Ready-to-Print

Tento priečinok obsahuje iba skontrolované výrobné exporty pre 5s3a.

Carrier v1 sem bude presunutý po úspešnom STL exporte, kontrole geometrie a potvrdení rastra montážnych otvorov voči DU bezel v2.

## Uvoľnené diely

- `737-MIP-CAL-001_M3-calibration-coupon_v1.stl` – vytlačiť 1 ks ako prvý diel projektu.
- `POKYNY_PRE_5s3a.md` – kompletné nastavenie tlače a postup vyhodnotenia testu.
- `Backlight-Test-v1/` – prvý trojvrstvový test podsvietenia; 3 STL a samostatný tlačový návod.
- `VYSLEDOK_5s3a.md` – výsledok CAL-001; M3 priechodzí otvor 3,2 mm potvrdený pre sivý Anycubic PETG, flow 0,96.
- `PFD-ND-Alignment-Fit-Check-v1/` – CAL-003, deväť malých dielov na overenie carrier/bezel/fascia geometrie a medzery pred veľkou tlačou.

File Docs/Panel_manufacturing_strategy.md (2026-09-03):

# Stratégia výroby panelov

Rozhodnuté 2026-09-03 (5s3a + patr3s). Týka sa všetkých predných panelov
s popismi a nosnej konštrukcie MIP.

## Rozhodnutia

1. **Skriňa, rámy a konzoly** sa vyrobia CNC frézovaním z **Forexu** a nalakujú.
2. **Predné panely s popismi sa tlačia**, nekupujú a nerobia z akrylátu.
3. **Popisy sa robia multicolor**, nie prierezom cez čiernu dosku.
4. **Zostávame pri parametrickom OpenSCAD zdrojáku**, cudzie STL nekupujeme.

---

## 1. Delenie výroby

| Časť | Technológia | Prečo |
|---|---|---|
| Skriňa MIP, rámy, konzoly, prepážky | Forex CNC + lak | Tabuľa 2 × 3 m, veľký diel vyjde v jednom kuse bez škár |
| Svetlotesné škatule za panelmi | tlač | 3D geometria, priehradky medzi popismi, kanály na LED |
| **Predné panely s popismi** | **tlač, multicolor** | viď sekcia 2 |
| Bezely, puzdrá gombíkov, držiaky encoderov | tlač | hĺbka, závity, dosadacie plochy |

### Prečo Forex nejde na predné panely

Forex je uzavretobunková PVC pena — nepriehľadná, svetlo v nej zaniká.
Vyfrézovaný popis s LED za ním nesvieti. Forex ide **len na nepodsvietené
konštrukčné diely**.

### Pozor pri Forexe

Je mäkký. Skrutka v ňom nedrží, heat-set vložka sa neuchytí, hrana sa dá
zatlačiť nechtom. Všade, kde ide o moment (gombík, encoder) alebo kde sa
bude panel často odoberať, treba **tlačenú alebo hliníkovú podložnú dosku
so závitom**. Neskrutkovať priamo do Forexu.

---

## 2. Multicolor popisy namiesto stencil fontu

### Problém so súčasným riešením

Stencil font v `labels_2d()` bol núdzový obchvat okolo voľných ostrovčekov
vo `dark_face()`. Pri jednom testovacom kupóne to prejde, pri celom kokpite nie:

- reálne 737 panely stencil font nemajú, majú čistý gotický
- stencilové písmo bude na každom paneli a bude to vidieť
- obmedzuje to výber fontu na celý projekt

### Riešenie

5s3a má **ACE Pro so štyrmi cievkami**. Popisy sa vytlačia ako **samostatná
farba v tej istej vrstve**, nie ako prierez.

Z jedného `.scad` sa exportujú dva STL so zdieľaným počiatkom:

| Export | Obsah |
|---|---|
| `*-face-black.stl` | doska mínus objem písma |
| `*-face-legends.stl` | len objem písma |

V sliceri sa načítajú ako **jeden objekt s časťami** a priradí sa filament
na časť.

### Zmena v CAD

Súčasný stav — písmo rezané cez celú hrúbku:

```scad
module dark_face() {
    difference() {
        linear_extrude(face_t) rounded_rect_2d([panel_w,panel_h],corner_r);
        mounting_holes(face_t);
        translate([90,31,-0.1]) cylinder(h=face_t+0.2,d=encoder_hole);
        linear_extrude(face_t+0.2) labels_2d();   // <- necháva ostrovčeky
    }
}
```

Navrhovaná zmena — rovnaký `difference()`, ale pribudne modul na samotné písmo
a `labels_2d()` sa vráti na normálny font:

```scad
module face_legends() {
    linear_extrude(legend_t) labels_2d();
}
```

plus nová vetva v `part` prepínači na export.

### Čo sa tým získa

| | Prierez + stencil | Multicolor |
|---|---|---|
| Voľné ostrovčeky | nutný stencil font | **žiadne**, všetko je spojené |
| Typografia | obmedzená na stencil | **akýkoľvek font** |
| Difúzia | cez otvor, ostrá hrana | cez biely plast, mäkká |
| Počet vrstiev | base + difúzor + face | **base + face** |

Samostatný difúzor tým odpadá — biele písmená sú samy difúzorom. Menej dielov,
menej skrutiek, tenší panel.

---

## 3. Hrúbka bieleho písmena — dve varianty na otestovanie

5s3a empiricky overil, že **na difúziu je optimum 0,4 mm bielej PETG**
(2 vrstvy pri 0,20 mm). Pri hrubšej vrstve svetlo výrazne ubúda.

Písmeno cez celú hrúbku face vrstvy by malo 1,2 mm, teda **3× viac než optimum**.
Preto treba porovnať dve varianty:

### Varianta A — písmeno cez celú hrúbku

`legend_t = face_t`. Jednoduchšie, jeden objem. Riziko: tmavšie popisy.

### Varianta B — písmeno 0,4 mm vpredu, zvyšok otvorený

`legend_t = 0.4`, za ním zostáva 0,8 mm otvorená dutina v čiernej doske.

Tlačí sa **lícom na podložku**: prvé dve vrstvy sú biele písmo + čierne okolie,
ďalšie vrstvy už len čierne s otvorom nad písmom. Žiadne mostíky, žiadne
podpery. Tá 0,8 mm dutina navyše svetlo trochu usmerní.

**Návrh:** vytlačiť obe varianty na `Backlight_test_panel_v1` a porovnať.
Kupón na to existuje a momentálne je aj tak blokovaný — týmto sa z neho stane
užitočný A/B test namiesto opravy stencil fontu.

---

## 4. Overiť pred rozbehnutím celého MIP

**Šírka ťahu písma proti priemeru trysky.**

`CLAUDE.md` má pravidlo ≥ 0,6 mm na embosované písmo. Boeing panelové popisy
majú výšku písmen ~3–4 mm a ťahy okolo 0,5 mm — pri 0,4 mm tryske je to
jedna extrúzia, teda na hrane použiteľnosti.

Zmerať najtenší ťah v reálnej veľkosti na jednom paneli. Ak vyjde pod 0,6 mm,
sú dve možnosti:

- **0,2 mm tryska** na predné panely
- písmo mierne zväčšiť

Lepšie to zistiť teraz než po desiatich vytlačených paneloch.

---

## 5. Prečo nekupujeme cudzie súbory

Zvažovali sme kúpiť hotové panely od 737DIYSIM. Zamietnuté, lebo predávajú
prevažne STL a my potrebujeme do geometrie zasahovať:

- font sa v STL nezmení
- na multicolor sa STL nerozdelí — treba dva objemy z jedného modelu
- nepasuje to na našu Forexovú skriňu, ktorú si robíme vlastnú
- `m3_clearance` na našich 3,2 mm sa neprenastaví

Parametrický OpenSCAD zdroják tieto štyri veci umožňuje, STL nie.

**Napriek tomu stojí za to kúpiť jeden ich panel ako rozmerovú referenciu.**
Za pár eur je odladená geometria — rozteče otvorov, veľkosti výrezov pre
encodery, proporcie popisov. Netlačiť, len premerať proti nášmu návrhu.
Najlacnejší spôsob, ako overiť, či naše čísla sedia na reálny 737.

Ak by predávali aj STEP alebo zdrojáky, oplatí sa to prehodnotiť — vtedy sa
to dá upraviť. Overiť v popise produktu, čo je v balíku.

---

## Nadväzujúce úlohy

| # | Úloha | Kto |
|---|---|---|
| 1 | Prekresliť `dark_face()` na dva exporty, zahodiť stencil font | patr3s |
| 2 | Pripraviť varianty A a B hrúbky písmena na backlight kupón | patr3s |
| 3 | Vytlačiť a porovnať A/B, vybrať `legend_t` | 5s3a |
| 4 | Zmerať najtenší ťah písma proti 0,4 mm tryske | 5s3a |
| 5 | Kúpiť jeden referenčný panel na premeranie | — |

Úloha 1 zároveň ruší blokujúcu chybu s voľnými ostrovčekmi
z `Ready-to-Print/VYSLEDOK_5s3a.md`, sekcia 3.1.

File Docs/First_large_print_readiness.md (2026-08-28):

# Pripravenosť pred prvou väčšou tlačou

## Môže sa tlačiť hneď

- M3 kalibračný diel: 1 ks, už v `Ready-to-Print`.
- Backlight test panel v1: základňa 1 ks, tmavá face vrstva 1 ks, difúzor 1 ks. Je to technologický test, nie finálny rozmerový panel.
- PFD/ND CAL-003 alignment fit-check: 1 sada deviatich malých dielov, bez heat-set vložiek.

## STL sú pripravené, ale ešte sa nemajú tlačiť ako finálne

- PFD carrier a ND carrier: čakajú na M3/heat-set kalibráciu a overenie rastra DU bezelu.
- DU bezel v3: čaká na overenie rastra štyroch servisných otvorov proti carrieru.
- BenQ PETG VESA cradle: `HOLD/DO NOT PRINT`; nahradí ho pevný oceľový VESA 100 nosník a nenosné tlačené dorazy.
- Dual-concentric knob set: čaká na presné rozmery hriadeľov enkódera.
- Kompletná fascia v1: CAD/STL hotové, čaká na výsledok CAL-003.

## Predbežný spojovací materiál pre celý PFD+ND modul

| Použitie | Predbežný počet |
|---|---:|
| M3 skrutky pre dva bezely | 8 |
| M3 skrutky pre dve stredové spojky | 4 |
| M3 skrutky pre dve horné konzoly | 4 |
| M3 skrutky pre bočné ramená a zadné krídla | 16 |
| M3 skrutky pre spodné stabilizátory | 4 |
| M3 rezerva | minimálne 12 |
| **M3 spolu** | **48 ks odporúčané minimum** |
| VESA skrutky do monitora | 4 ks, pravdepodobne M4 – overiť závit a dĺžku |

Odporúča sa sada M3 × 6/8/10/12/16/20 mm, široké M3 podložky a najmenej 20 M3 matíc. Presné dĺžky sa vyberú pri suchej montáži.

## Heat-set vložky

Predbežne treba približne 24–32 kusov M3 plus rezervu. Nekupovať náhodný rozmer: vybrať jeden konkrétny typ a oznámiť jeho vonkajší priemer a dĺžku. Kalibračný model sa pred tlačou upraví na jeho skutočnú dĺžku.

## Čo ešte zmerať alebo overiť

Na monitore už netreba opakovať celkové rozmery ani aktívnu plochu. Zostáva:

1. potvrdiť závit všetkých štyroch VESA otvorov,
2. zistiť maximálnu bezpečnú hĺbku zaskrutkovania,
3. odfotiť zadnú stranu so zapojeným VGA a napájacím káblom,
4. zmerať, koľko priestoru potrebuje každý konektor a ohyb kábla,
5. overiť, či zadný kryt nemá výstupok hrubší než uvedených 60 mm.

Pre dual-concentric panel treba neskôr zmerať priemer závitového puzdra enkódera, dĺžku a priemer oboch hriadeľov, tvar hriadeľov a vzdialenosť matice od prednej plochy panelu.

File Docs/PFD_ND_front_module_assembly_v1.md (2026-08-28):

# Complete PFD/ND front module assembly v1

## Front-to-rear stack

1. Dark fascia face segments, 1,0 mm.
2. Optional 0,4 mm fascia diffuser segments under future legends.
3. Light fascia base segments, 3,2 mm.
4. Two DU bezel v3 stacks installed in the fascia cutouts.
5. PFD and ND carrier frames behind the fascia.
6. BenQ front active plane aligned to the two carrier/bezel openings.
7. Fixed steel VESA 100 × 100 mm bracket attached to the structural MIP frame.

The steel bracket carries the monitor. Printed carrier/fascia parts establish XY alignment and light side contact only.

## Assembly datums

- Monitor-body top-left is `(0,0)`.
- PFD center: `(118,1; 134,0)` mm.
- ND center: `(327,9; 134,0)` mm.
- Carrier Y origin: 24,4 mm.
- Left carrier X origin: 0 mm.
- Right carrier X origin: 225,8 mm.
- Left bezel origin: `(16,5; 32,4)` mm.
- Right bezel origin: `(226,3; 32,4)` mm.

## Service sequence

1. Remove the front M3 bezel screws.
2. Remove bezel stacks and fascia segments as required.
3. Disconnect the independent COB/dimmer harness through the service connectors.
4. From the rear, disconnect VGA and power.
5. Support the monitor, loosen the steel VESA bracket and remove the monitor rearward.

Printed parts must never be used as the sole monitor support.

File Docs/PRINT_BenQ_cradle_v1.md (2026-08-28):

# Tlačové pokyny – ARCHÍV / NEPOUŽÍVAŤ

Tlačený PETG cradle má stav `HOLD/DO NOT PRINT`. Hlavné zaťaženie monitora bude niesť pevný oceľový VESA 100 × 100 mm držiak. Nasledujúce údaje zostávajú iba ako archív pôvodného návrhu.

## Materiál

Použiť PETG. Prednostne čierny PETG; biely PETG je funkčne rovnocenný a diely možno po odmastení, jemnom prebrúsení a základe na plasty nastriekať. Všetky nosné diely jednej zostavy sa odporúča tlačiť z rovnakej značky a šarže materiálu.

## Nastavenie

- Tryska 0,4 mm.
- Vrstva 0,20 mm.
- 5 stien/perimetrov.
- 6 horných a 6 spodných vrstiev.
- 30 % gyroid pre VESA platňu, krídla a hĺbkové ramená.
- 25 % gyroid pre spodné stabilizátory.
- Bez podpier; všetky výrobné STL sú orientované naplocho.
- Mierka 100 %, bez automatického zväčšovania otvorov slicerom.
- Teploty podľa overeného profilu konkrétneho PETG.

## Počty dielov

| Diel | Počet |
|---|---:|
| VESA plate | 1 |
| Rear wing | 4 |
| Depth arm | 4 |
| Bottom stabilizer | 2 |
| PFD carrier | 1 |
| ND carrier | 1 |
| Stredová spojka carrieru | 2 |
| Horná konzola EFIS/MCP | 2 |

## Kontrola po tlači

1. Diely musia ležať rovno bez zdvihnutých rohov.
2. M3 skrutka musí prejsť zvolenými priechodzími otvormi rukou.
3. Heat-set vložky osadiť kolmo podľa výsledku kalibračného dielu.
4. VESA platňa nesmie byť prehnutá; skontrolovať pravítkom cez obe diagonály.
5. Všetky drážky začistiť iba od voľných vlákien, nezväčšovať ich vrtákom pred skúšobnou montážou.
6. Prvú montáž robiť bez monitora, potom s monitorom a voľne založenými skrutkami.

## Povrchová úprava

Funkčné styčné plochy, heat-set kapsy, závity a dosadacie plochy podložiek sa nestriekajú. Pred farbením sa zamaskujú. Lakovať až po úspešnej suchej montáži celej zostavy.

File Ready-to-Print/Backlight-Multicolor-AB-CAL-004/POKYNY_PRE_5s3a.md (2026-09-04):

# CAL-004 – multicolor A/B backlight test

Cieľom je rozhodnúť, či biele PETG legendy môžu zároveň fungovať ako difúzor,
bez samostatnej difúznej dosky. Test neoveruje finálny Boeing font ani finálny
layout; tie zostávajú `PROVISIONAL`.

## Súbory a dva multicolor objekty

Základňu vytlačiť raz z bieleho alebo svetlého PETG:

- `737-MIP-CAL-004_backlight-base.stl`

V sliceri vytvoriť dva samostatné multicolor objekty. STL každej dvojice
načítať ako časti jedného objektu; všetky majú spoločný počiatok a mierku.

### Variant A – biela legenda cez celú hrúbku 1,0 mm

- čierna časť: `737-MIP-CAL-004_face-black.stl`
- biela časť: `737-MIP-CAL-004_legends-A-1.0mm.stl`

### Variant B – biela legenda iba 0,4 mm na prednej strane

- čierna časť: `737-MIP-CAL-004_face-black.stl`
- biela časť: `737-MIP-CAL-004_legends-B-0.4mm.stl`

Varianty tlačiť lícom na podložku. Pri variante B sú prvé dve vrstvy biele
legendy a čierne okolie; nad legendami zostáva 0,6 mm otvor v čiernej vrstve.

## Profil

- Anycubic PETG: čierny + biely, bez striekania.
- Tryska 0,4 mm, vrstva presne 0,20 mm.
- Mierka 100 %, bez podpier.
- 4 steny; face objekty 100 % výplň, základňa 25 % gyroid.
- Pre overený Anycubic PETG: 230 °C tryska, 75 °C podložka, flow 0,96.
- Skontrolovať purge tower a dostatočné prečistenie po zmene čierna/biela.

## Svetlo a zostavenie

Do predného kanála základne vložiť dva rovné približne 90 mm úseky bieleho
12 V COB LED pásika širokého 5 mm. Pásik nepripájať na Arduino pin. Použiť
12 V zdroj aspoň 0,5 A. Face variant položiť priamo na základňu a dočasne
uchytiť štyrmi M3 skrutkami, podložkami a maticami.

## Čo porovnať

- čitateľnosť vypnutého panelu za denného svetla,
- jas a rovnomernosť popisov v tme aj pri izbovom svetle,
- presvitanie čiernej plochy a svetelné lemy,
- viditeľnosť vrstiev alebo bodov LED,
- čistotu písmen a symbolu po multicolor tlači,
- najtenší reálne vytlačený ťah písma.

Výsledok zapísať osobitne pre A a B a priložiť fotografie s rovnakým
nastavením expozície. Samostatný difúzor sa z finálneho návrhu odstráni až
vtedy, keď jeden variant týmto testom prejde.

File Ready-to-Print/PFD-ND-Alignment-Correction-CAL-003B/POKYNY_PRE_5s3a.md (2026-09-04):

# CAL-003B – oprava stredovej fascie a seam spojky

Toto je lacná opravná tlač po meraní CAL-003. Pôvodné diely, ktoré už 5s3a
vytlačil, sa použijú znova. Netreba opakovať všetkých deväť dielov.

## Vytlačiť

- 1× `737-MIP-CAL-003B_fascia-center_v1.1.stl`
- 1× `737-MIP-CAL-003B_fascia-seam-joiner_v1.1.stl`

Materiál môže byť ľubovoľný dostupný PETG; farba pri tomto mechanickom teste
nie je dôležitá. Použiť rovnaký profil ako CAL-003: tryska 0,4 mm, vrstva
0,20 mm, 4 steny, 5 horných/spodných vrstiev, 25 % gyroid, bez podpier,
mierka 100 %, 230 °C / 75 °C a flow 0,96 pre rovnaký Anycubic PETG.

## Overenie

1. Nový stredový diel vložiť medzi pôvodné bezel kupóny. Spodný jazyk musí
   vojsť do medzery a obe krajné nohy musia súčasne dosadnúť na horné plochy
   bezelov bez kolízie. Jazyk má odskok 4,8 mm.
2. Skontrolovať vôľu jazyka: nominálne 0,20 mm na každej strane.
3. Novou seam spojkou spojiť pôvodné `fascia_seam_left/right`. Obe skrutky
   musia prejsť naraz; ich rozteč je opravená na 20 mm.
4. Použiť M3 skrutky s podložkami a maticami. Montážne otvory majú 3,4 mm,
   aby sa pri viacotvorovom spoji nesčítavali výrobné odchýlky.
5. Zapísať, či diely sadli bez úpravy, a odfotiť zostavu spredu aj zboku.

Ak oba body sedia, CAL-003B je prijatý a rovnaké opravy možno preniesť do
veľkej fascie. Kritické rozmery 6,60 mm a 39,99 mm už potvrdil CAL-003.

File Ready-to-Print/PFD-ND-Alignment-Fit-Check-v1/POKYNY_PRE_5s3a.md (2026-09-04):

# PFD/ND alignment fit-check v1

> **SUPERSEDED / DO NOT REPRINT:** CAL-003 was measured successfully, but two
> parts contain assembly errors. Use `PFD-ND-Alignment-Correction-CAL-003B`
> for the corrected center tongue and seam joiner.

## Purpose

This inexpensive coupon verifies the final center geometry before printing the complete 445 mm module:

- 6,6 mm physical carrier/bezel gap,
- 40,1 mm visible-opening gap,
- carrier opening edge,
- bezel stack edge,
- fascia center mask,
- M3 carrier joiner and fascia seam joiner.

No heat-set inserts are required. Use ordinary M3 through-screws, washers and nuts.

## Print quantities

Print one of every STL in this folder except this instruction file: 9 small parts total.

## Material and profile

- PETG, preferably the same Anycubic PETG/profile used for CAL-001.
- 0,4 mm nozzle, 0,20 mm layer.
- 4 walls, 5 top/bottom layers, 25 % gyroid.
- No supports, 100 % scale.
- Use the verified profile: 230 °C nozzle, 75 °C bed, flow 0,96, if the same grey Anycubic PETG is used.

## Assembly and measurement

1. Join `carrier_left` and `carrier_right` from behind with `carrier_joiner`; set the clear gap to exactly 6,6 mm before tightening.
2. Fit the two bezel coupons on the front carrier edges with M3 screws/nuts.
3. Insert the narrow fascia-center coupon between the bezel edges. It must enter without force and must not visibly rattle.
4. Measure the physical bezel-edge gap: target 6,6 mm.
5. Measure the two represented visible-opening edges: target 40,1 mm.
6. Assemble `fascia_seam_left` and `fascia_seam_right` with the rear seam joiner. The front faces must remain flush.
7. Photograph the assembly from the front, rear and side and record actual dimensions.

## Acceptance

- Carrier gap: 6,6 mm ±0,2 mm.
- Visible opening gap: 40,1 mm ±0,3 mm.
- Front fascia seam step: maximum 0,2 mm.
- M3 screws pass by hand through the 3,2 mm holes.
- No cracking or forced fit.

Do not print the complete fascia/carrier until this coupon is accepted.

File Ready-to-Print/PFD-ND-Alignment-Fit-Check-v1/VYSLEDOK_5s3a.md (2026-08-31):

# Výsledok CAL-003 – PFD/ND alignment fit-check v1

Tlačil a meral: 5s3a, 2026-08-31. Anycubic Kobra X, tryska 0,4 mm.

## Verdikt

**Všetky akceptačné kritériá splnené.** Geometria stredu je potvrdená, veľký
445 mm modul môže ísť ďalej.

Zároveň sú v CAD **tri chyby**, ktoré znemožnili fyzicky vykonať dva kroky
montáže. Kritériá sa dali overiť meraním, ale diely v tejto podobe nesadnú.

| Kritérium | Cieľ | Namerané | |
|---|---|---|---|
| Medzera medzi bezelmi | 6,6 ±0,2 | **6,60** | OK |
| Viditeľný otvor | 40,1 ±0,3 | **39,99** | OK |
| Stupeň v prednom spoji fascie | max 0,2 | **0,01** | OK |
| M3 skrutky cez otvory 3,2 | rukou | tesnejšie, viď nižšie | pozn. |
| Praskliny, násilné lícovanie | žiadne | žiadne | OK |

## Nastavenie tlače

Podľa pokynov, na overenom profile z CAL-001:

| Položka | Hodnota |
|---|---|
| Filament | Anycubic PETG, sivý |
| Tryska / podložka | 230 °C / 75 °C |
| Flow | 0,96 |
| Vrstva | 0,20 mm |
| Steny | 4 |
| Horné/spodné vrstvy | 5 |
| Výplň | 25 % gyroid |
| Podpery | žiadne, 100 % mierka |

Všetkých 9 dielov na jednu podložku, súčet plôch 24 456 mm² z 260 × 260 mm.

## A. Jednotlivé diely

| Diel | Rozmer | Nominál | Namerané |
|---|---|---|---|
| carrier_left | šírka × výška | 70,00 × 80,00 | 70,02 × 80,00 |
| carrier_left | hrúbka | 5,00 | 5,03 |
| carrier_left | vnútorná lišta | 16,25 | 16,23 |
| carrier_right | šírka × výška | 70,00 × 80,00 | 70,02 × 79,98 |
| carrier_right | hrúbka | 5,00 | 5,00 |
| carrier_right | vnútorná lišta | 16,25 | 16,32 |
| bezel_left | šírka × výška | 30,00 × 80,00 | 30,09 × 80,00 |
| bezel_left | hrúbka | 4,80 | 4,79 |
| bezel_left | vnútorná lišta | 16,75 | 16,84 |
| bezel_right | šírka × výška | 30,00 × 80,00 | 30,04 × 79,96 |
| bezel_right | hrúbka | 4,80 | 4,77 |
| bezel_right | vnútorná lišta | 16,75 | 16,79 |
| fascia_center | šírka jazyka | 6,20 | **6,20** |
| fascia_center | celková šírka | 26,00 | 26,05 |
| carrier_joiner | dĺžka | 92,00 | 91,95 |
| fascia_seam_left / right | šírka | 60,00 | 59,99 / 60,00 |

### Dôležité: zmrštenie z CAL-001 na tieto diely neplatí

CAL-001 sa zmrštil o **0,25 %**. Tieto diely vyšli **na nominál alebo mierne
nad** (70 → 70,02, 80 → 80,00, 60 → 59,99).

Pravdepodobná príčina: CAL-001 je plný 6 mm blok, kým tieto sú tenké platne
s 25 % gyroidom. Menej materiálu, menšie zmršťovacie napätie.

**Dôsledok:** obava z 0,5 mm manka na 203,2 mm DU bezeli je pri tomto profile
neopodstatnená. XY compensation netreba. Zmrštenie treba brať ako veličinu
závislú od profilu a objemu dielu, nie ako konštantu materiálu.

### Meranie lišty vs. meranie zostavy

Súčet lišt dáva 6,60 + 16,84 + 16,79 = **40,23**, ale zostava reálne meria
**39,99**. Rozdiel 0,24 mm.

Dôveryhodnejšie je meranie zostavy — je to jedno priame meranie toho, na čom
záleží. Lišty sa merajú cez hranu otvoru, ktorá má po tlači mierny rádius,
a posuvka tam číta o niečo viac. Pri ďalších kupónoch odporúčam kritické
rozmery merať na zostave, nie skladať ich zo súčtu dielov.

## B. M3 priechodzie otvory

Všetkých 12 otvorov priechodných. Skrutka prvýkrát prejde **jemným ľahkým
skrutkovaním**, po prvom prechode už ide rukou. Diely držia dobre a nehrkajú.

Pre tento kupón je to skôr výhoda — spoje sa samy vycentrujú. **Pre veľký
modul to ale odporúčam prehodnotiť:** pri spoji s viacerými otvormi naraz sa
odchýlky sčítajú a zostavu nepolícuješ, ak je každý otvor na interferenciu.
Priechodzí otvor má mať vôľu práve na pohltenie tolerancie.

Návrh: **3,2 mm ponechať tam, kde ide o presnú polohu** (bezel voči carrieru),
**3,4 mm na spoje s viacerými otvormi naraz.**

Poznámka: kalibrácia 3,2 mm z CAL-001 bola robená na **default profile**,
zatiaľ čo tento kupón sa tlačil na **4 steny**. Viac stien otvory utiahne.
Kalibrácia priechodzieho otvoru je viazaná na profil, nielen na materiál.

---

# Chyby v CAD

## 1. `fascia_center` sa nedá zasunúť do medzery — blokujúce

`fascia_center` je plochá doska hrúbky 3,2 mm. Jazyk aj obe krajné nohy ležia
v **jednej rovine**:

- nohy: 26 mm široké, z = 0 … 3,2
- jazyk: 6,2 mm široký, z = 0 … 3,2

Nohy dosadnú na horný povrch bezelov vo výške 9,8 mm, takže jazyk skončí
**nad** medzerou, nie v nej. Krok 3 pokynov *„Insert the narrow fascia-center
coupon between the bezel edges"* sa vykonať nedá.

Aby to fungovalo, jazyk musí vyčnievať pod rovinu nôh o hrúbku bezelu,
teda **4,8 mm**. Taký odskok v module nie je.

**Kritérium sa napriek tomu podarilo overiť meraním:**

- medzera medzi bezelmi: **6,60 mm**
- jazyk: **6,20 mm**
- vôľa: **0,40 mm**, teda presne 0,20 mm na stranu podľa návrhu

Rozmerovo je to teda správne. Po doplnení odskoku v Z diel sadne.

## 2. `fascia_seam_joiner` má nesediacu rozteč dier — blokujúce

Odmerané priamo z STL v `Ready-to-Print`:

| Diel | Poloha diery | Rozteč po zložení |
|---|---|---|
| fascia_seam_left | x = 50,0 | **20 mm** |
| fascia_seam_right | x = 70,0 | |
| fascia_seam_joiner | x = 10,0 a 60,0 | **50 mm** |

Obe polovice majú dieru 10 mm od škáry, teda 20 mm od seba. Spojka ich má
50 mm od seba. Rozdiel 30 mm — vždy sadne len jedna skrutka.

Stupeň v spoji sa dal odmerať aj bez spojky (polovice zrazené na tupo),
výsledok **0,01 mm**. Spojka drží diely pri sebe, rovinnosť škáry určujú
samotné diely.

## 3. `assembly_preview()` umiestňuje `fascia_center` o 3,1 mm vedľa — kozmetické

```scad
translate([coupon_w + (carrier_gap - fascia_center_w)/2 - 13, ...])   // 57,2
```

Mieša sa tu vôľa na stranu `(carrier_gap - fascia_center_w)/2 = 0,2`
s polovicou medzery `carrier_gap/2 = 3,3`. Správne má byť:

```scad
translate([coupon_w + carrier_gap/2 - 13, ...])                       // 60,3
```

Jazyk tak v preview vychádza v strede na 70,2 namiesto 73,3 a prekrýva
`bezel_left`.

Toto je pravdepodobne dôvod, prečo sa chyba č. 1 neodhalila — v preview diel
vyzeral ako maska ležiaca navrchu a nebolo vidieť, že sa má zasúvať.

Poznámka: `assembly_preview()` neobsahuje ani tri seam diely, takže chyba
č. 2 tiež nebola vizuálne skontrolovateľná. Odporúčam do preview doplniť
všetkých 9 dielov.

---

# Čo potrebujeme od patr3s

| # | Vec | Blokuje |
|---|---|---|
| 1 | Odskok jazyka `fascia_center` o 4,8 mm v Z | zasunutie fascie |
| 2 | Rozteč dier `fascia_seam_joiner` na 20 mm | spojenie seam polovíc |
| 3 | Oprava posunu v `assembly_preview()` | vizuálna kontrola |
| 4 | Doplniť seam diely do `assembly_preview()` | vizuálna kontrola |
| 5 | Zvážiť 3,4 mm otvory na viacotvorové spoje | veľký modul |
| 6 | Odmerať OD a dĺžku heat-set vložky | heat-set test |

Chyby 1 a 2 nemenia nič na akceptácii — rozmery sú overené meraním
a sedia. Ide o geometriu montáže, nie o presnosť tlače.

Fotografie posielam samostatne.

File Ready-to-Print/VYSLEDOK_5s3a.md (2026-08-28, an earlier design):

# Spätná väzba od 5s3a

Tlačiareň: Anycubic Kobra X, tryska 0,4 mm, podložka 260 × 260 mm.
Dátum: 2026-08-28.

---

# 1. CAL-001 – M3 kalibračný kupón v1 — VYTLAČENÉ

## Použitý materiál a nastavenie

| Položka | Hodnota |
|---|---|
| Filament | **Anycubic PETG, sivý** |
| Tryska | **230 °C** |
| Podložka | **75 °C** |
| Flow | **0,96** |
| Vrstva | 0,20 mm |
| Profil | default Anycubic Slicer Next |

Tlačené podľa pokynov: bez podpier, bez brimu, veľkou rovnou plochou na podložku,
mierka 100 %.

## Rozmerová kontrola

| Os | Nominál | Meranie | Odchýlka |
|---|---|---|---|
| dlhá | 84,00 mm | **83,82 mm** | −0,18 mm (−0,21 %) |
| krátka | 46,00 mm | **45,85 mm** | −0,15 mm (−0,33 %) |

Zmrštenie rovnomerné na oboch osiach. Rohy nezdvihnuté, otvory kruhové,
diel bez chýb.

## Spodný rad – M3 priechodzí otvor

**Najlepší stĺpec: 1 (3,2 mm).**

M3 skrutka prejde rukou bez sily, bez rezania závitu a nekýva sa do strán.
3,2 mm je zároveň spodná hranica rozsahu kupónu — je možné, že by prešlo
aj tesnejšie, ale kupón to už netestuje.

**Odporúčanie: `m3_clearance = 3.2` namiesto súčasných 3,4 mm.**

Tesnejší otvor uberá vôľu v rastri montážnych otvorov. Pri 203,2 mm bezeloch
sa to hodí — viď poznámka o zmrštení v sekcii 5.

## Horný rad – heat-set kapsa

**Netestované.** Vložky ešte nie sú kúpené (BOM ich vedie ako `TBD`),
osadenie a vyhodnotenie si robí patr3s sám.

### Tri veci, ktoré treba vedieť pred tým testom

1. **Hĺbka kapsy 4,2 mm počíta s vložkou dlhou ~4,0 mm.**
   Pod kapsou je 3,0 mm pilot, takže dlhšia vložka sa nemá kam schovať.
   Bežné M3 vložky typu CNC Kitchen / Voron majú **5,7 mm** — tie by trčali
   1,5 mm nad povrch a do 6 mm hrubého kupónu sa nezmestia vôbec.
   Pred testom odmerať dĺžku posuvkou.

2. **Rozsah 4,2 / 4,4 / 4,6 / 4,8 mm predpokladá vložku s OD ~4,0 mm.**
   Ak majú vložky OD 4,6 mm, stĺpce 3 a 4 sú nominál a väčšie — tie sa
   zaručene pretočia a test reálne vyhodnotí len dva stĺpce.

3. **Táto tlačiareň tlačí otvory blízko nominálu.** Dokazuje to stĺpec 1
   pri M3 — pri FDM sa bežne očakáva, že otvory vyjdú menšie, tu nie
   (flow 0,96, zmrštenie 0,25 %). Kapsy teda vyjdú skôr **voľnejšie**,
   než je zvykom. Pri výbere sa prikloniť k menším kapsám (4,2 / 4,4),
   inak hrozí pretáčanie vložky pod momentom.

---

# 2. Empirický nález k difúzii svetla

**Na difúziu stačia 2 vrstvy à 0,20 mm bielej PETG, teda 0,4 mm.**
Overené v praxi, dáva zatiaľ najlepší výsledok.

Toto má priamy dopad na `Backlight_test_panel_v1`:

| Prvok | Súčasný návrh | Poznámka |
|---|---|---|
| Materiál nad LED kanálom v základni | **1,9 mm** (`base_t 3.2` − kanál 1,3) | ~5× viac, než treba |
| Samostatný difúzor `diffuser_t` | **0,8 mm** | 2× viac, než treba |

1,9 mm bielej PETG nad LED-kami zožerie veľkú časť svetla. Panel bude tmavý
a bude to vyzerať ako slabé LED, pričom problém bude v hrúbke steny.

**Návrh:** kanál prehĺbiť tak, aby nad ním zostalo ~0,4–0,6 mm materiálu,
alebo difúziu riešiť samostatnou 0,4 mm vrstvou a základňu nad LED úplne
otvoriť. Vieme vytlačiť obe verzie a porovnať, ak pošleš druhý variant.

---

# 3. Backlight-Test-v1 — zatiaľ NEVYTLAČENÉ

Kontrolované pred tlačou, tri nálezy. Prvý je blokujúci.

## 3.1 Face vrstva má 5 voľných ostrovčekov — blokujúce

`737-MIP-CAL-002A_backlight-face_v1.stl` obsahuje **6 samostatných shellov**
namiesto jedného. Nápisy sú v `dark_face()` rezané cez celú hrúbku
(`linear_extrude(face_t+0.2) labels_2d()`), takže vnútra písmen zostanú
ako nezávislé kusy:

| Písmeno | Poloha x (mm) | Poloha y (mm) |
|---|---|---|
| `D` v DUAL | 80,5–83,2 | 42,2–46,0 |
| `D` v DIM | 23,3–26,5 | 21,8–26,3 |
| `P` v PANEL | 14,4–17,4 | 42,2–44,7 |
| `A` v DUAL | 92,6–94,3 | 43,6–46,1 |
| `A` v PANEL | 21,4–23,6 | 41,4–44,7 |

Sú to voľné kúsky ~2–3 mm × 1 mm bez spojenia so zvyškom dielu. Tryska ich
pri tlači posunie po podložke. Diel sa v tejto podobe nedá vytlačiť.

**Riešenie** — jedno z dvoch:
- stencil font s mostíkmi v písmenách, alebo
- text nechať ako priehlbinu (napr. 0,6 mm) namiesto prierezu

Voľba závisí od toho, či má cez znaky svietiť svetlo priamo, alebo cez
tenkú stenu. Vzhľadom na nález v sekcii 2 (0,4 mm bielej PETG difunduje dobre)
by druhá možnosť mohla byť lepšia aj opticky — znaky by svietili rovnomerne
bez ostrých hrán.

## 3.2 Poradie vrstiev — pokyny si protirečia s CAD-om

`POKYNY_PRE_TLAC.md`, bod 2 zostavenia:

> Difúzor položiť na svetlú základňu a navrch položiť čiernu face vrstvu.

Ale `assembly_preview()` v `.scad` má difúzor **pod** základňou:

```scad
translate([4,4,-diffuser_t]) diffuser();
```

Tam difúzor nie je medzi LED a pozorovateľom — kryje LED kanál zozadu, teda
funguje skôr ako zadný kryt/reflektor a difúziu robí samotná 1,9 mm základňa.
To je konzistentný návrh, ale nie ten, čo popisujú pokyny. **Ktoré platí?**

## 3.3 LED kanál má 1,4 mm — obmedzuje výber pásika

`linear_extrude(1.4)` v `light_base()`.

Rozmery kanála odvodené z CAD:

| Parameter | Hodnota |
|---|---|
| Šírka drážky | 6 mm |
| Hĺbka drážky | 1,4 mm |
| Dráha stredom | 98 × 40 mm, obvod ~276 mm |
| Dĺžka dlhej strany | ~98 mm |
| Servisný vývod | 8 × 1,6 mm, pravý okraj |

Do 6 × 1,4 mm sa **5050 pásik nezmestí** (10 mm široký, 2,0–2,5 mm hrubý).
Štandardný 8 mm pásik tiež nie — je širší než drážka.

**Čo do toho ide: COB LED pásik, 12 V, biely, šírka 5 mm.**

- **COB** (chip-on-board) má súvislú vrstvu luminoforu namiesto jednotlivých
  diód. Test sa priamo pýta *„či vidno jednotlivé body LED"* — s COB-om táto
  otázka odpadne.
- **12 V**, nie 24 V: 12 V pásiky sa strihajú po 25–50 mm, 24 V po 100 mm.
  Dlhá strana má 98 mm, s 24 V sa netrafíme.
- **5 mm šírka**, nie štandardných 8 mm — do 6 mm drážky.

**Upozornenie na hrúbku:** holý pásik má ~1,0–1,2 mm, ale s 3M lepiacou
páskou na chrbte **1,4–1,6 mm**, teda na hranici alebo cez ňu. Buď pásik bez
lepidla, alebo prehĺbiť kanál na 2,0 mm. Základňa má 3,2 mm, priestor tam je —
a podľa sekcie 2 by sa aj tak mal prehĺbiť.

**Poznámka k zapojeniu na test:** pásik sa neohýba do strán, len pozdĺž.
Obvod dokola by znamenal strih a spájku v štyroch rohoch. Na test stačia
**dva rovné kusy po ~90 mm na dve dlhé strany**, rohy vynechať. ~18 cm pásika
je do 2 W, stačí 12 V adaptér od 0,5 A.

## 3.4 Rozmery overené proti podložke

| Diel | Rozmer (mm) | Stav |
|---|---|---|
| CAL-001 kupón | 84,0 × 46,0 × 6,0 | OK |
| CAL-002 base | 120,0 × 62,0 × 3,2 | OK |
| CAL-002A face | 120,0 × 62,0 × 1,0 | OK |
| CAL-002B diffuser | 112,0 × 54,0 × 0,8 | OK |

Montážne otvory aj otvor pre encoder si medzi base, face a diffuser
v zostave sedia — kontrolované, bez posunu.

---

# 4. Pripomienka k BenQ VESA cradle v1

**Návrh: nosnú funkciu neriešiť tlačeným dielom.**

Dva technické dôvody:

## 4.1 PETG tečie pod dlhodobým statickým zaťažením

VESA platňa 170 × 170 × 7 mm bude mesiace niesť monitor. PETG má výrazný
**creep** — pomaly sa dotvaruje pod konštantným zaťažením, aj hlboko pod
medzou pevnosti. `PRINT_BenQ_cradle_v1.md` rieši len rovinnosť po tlači:

> VESA platňa nesmie byť prehnutá; skontrolovať pravítkom cez obe diagonály.

O dotvarovaní v čase sa nehovorí nič. Platňa môže byť po tlači rovná
a po pol roku prehnutá.

## 4.2 Plynové rameno tu nie je alternatíva

Napadlo ma nahradiť cradle pneumatickým držiakom, ale nefunguje to z dvoch dôvodov:

- **Monitor je príliš ľahký.** 18,5" bez stojana váži cca 2–2,5 kg, väčšina
  plynových ramien má *minimálnu* nosnosť okolo 2 kg. Pod ňou pružina monitor
  tlačí hore a neudrží polohu.
- **Rameno je navrhnuté, aby sa hýbalo** — a to je presne to, čo tu nechceme.
  Celý zmysel cradlu je držať aktívnu plochu presne za DU výrezmi
  (posun hornej hrany 6,25 mm, slotované VESA otvory ±2,4 mm, skrutky sa
  doťahujú až *„po zarovnaní obrazu"*). Jedno drgnutie a zarovnanie je preč.

## 4.3 Návrh

**Pevný oceľový VESA 100 držiak** (stenový/plochý, bežne 8–15 €), prikrutený
na rám kokpitu. Nesie záťaž, nedotvaruje sa, nehýbe sa.

Z PETG sa potom vytlačia len **tenké podložky a dorazy na doladenie polohy**,
navrhnuté až po suchej montáži, keď bude vidieť skutočnú odchýlku.
Z 11 tlačených dielov (1 platňa + 4 krídla + 4 ramená + 2 stabilizátory)
by zostali možno 2 malé.

Vieme, že to mení rozhranie na PFD/ND carrier — zaťaženie by už nešlo cez
bočné ramená do okrajov carrieru. Preto je to pripomienka na zváženie,
nie hotové riešenie.

---

# 5. Poznámka k veľkým dielom

Pri nameranom zmrštení −0,25 % vyjde DU bezel s nominálom 203,2 mm ako
~202,7 mm, teda **0,5 mm manko cez celý panel**. Pri M3 priechodzích otvoroch
sa to schová, ale ak sa bezel lícuje na reálny hardvér, treba s tým počítať.

XY size compensation vieme v sliceri zapnúť kedykoľvek. Zatiaľ nie je dôvod —
rovnomerné zmrštenie 0,25 % je pre PETG veľmi dobrý výsledok
(bežne 0,3–0,8 %).

Platí len pre **Anycubic PETG sivý**. Pri zmene značky alebo šarže premerať
znova, ako správne upozorňuješ v pokynoch.

---

# 6. Čo potrebujeme od patr3s

| # | Vec | Blokuje |
|---|---|---|
| 1 | Opraviť voľné ostrovčeky vo face vrstve (3.1) | tlač Backlight-Test-v1 |
| 2 | Potvrdiť poradie vrstiev — pokyny vs. CAD (3.2) | zostavenie testu |
| 3 | Zvážiť prehĺbenie LED kanála a stenu nad LED (2, 3.3) | výber pásika |
| 4 | Odmerať OD a dĺžku heat-set vložky (1) | heat-set test |
| 5 | Vyjadriť sa k BenQ cradle (4) | tlač 11 dielov |

Fotografie CAL-001 posielam samostatne.

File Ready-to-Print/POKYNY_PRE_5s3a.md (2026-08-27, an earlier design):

# Pokyny pre 5s3a – prvá skúšobná tlač

## Súbor

Vytlač:

`737-MIP-CAL-001_M3-calibration-coupon_v1.stl`

Počet: **1 kus**  
Rozmer hotového modelu: **84 × 46 × 6 mm**  
Mierka v sliceri: **100 % vo všetkých osiach**

## Materiál

Použi **PETG**.

- Prednostne môžeš použiť **čierny PETG**, pretože väčšina finálnych nosných častí MIP bude tmavá.
- Ak máš práve lepšie nastavený alebo otvorený **biely PETG**, pokojne použi biely. Na funkciu a kalibráciu farba nemá vplyv.
- Finálne diely bude možné po odmastení, jemnom prebrúsení a použití základu na plasty nastriekať požadovanou farbou.
- Na tento test nepoužívaj PLA, pretože rozmery otvorov chceme kalibrovať pre rovnaký PETG, z ktorého sa budú tlačiť nosné diely.

Poznač si výrobcu a presný typ použitého PETG. Pri zmene značky alebo profilu sa môžu otvory mierne zmeniť.

## Nastavenie tlače

- Tryska: **0,4 mm**
- Výška vrstvy: **0,20 mm**
- Steny/perimetre: **4**
- Horné vrstvy: **5**
- Spodné vrstvy: **5**
- Výplň: **20–25 % gyroid**
- Podpery: **vypnuté**
- Brim: zvyčajne netreba; použi ho iba ak sa PETG na tvojej podložke odliepa
- Teplota trysky a podložky: použi overený profil pre konkrétny PETG; ak ho nemáš, začni hodnotami odporúčanými výrobcom filamentu
- Chladenie: podľa overeného PETG profilu, nie naplno od prvej vrstvy
- Elephant-foot kompenzácia: podľa kalibrácie tlačiarne

Model polož veľkou rovnou spodnou plochou priamo na podložku. V sliceri ho neotáčaj na bok a nepridávaj podpery.

## Čo diel testuje

Pri pohľade zhora sú dva rady otvorov a štyri stĺpce zľava doprava:

| Stĺpec | Horný rad `HS` – heat-set kapsa | Spodný rad `M3` – priechodzí otvor |
|---:|---:|---:|
| 1 | 4,2 mm | 3,2 mm |
| 2 | 4,4 mm | 3,4 mm |
| 3 | 4,6 mm | 3,6 mm |
| 4 | 4,8 mm | 3,8 mm |

## Postup po vytlačení

1. Nechaj diel úplne vychladnúť a až potom ho zlož z podložky.
2. Otvory nevŕtaj ani nezačisťuj. Potrebujeme výsledok priamo z tlačiarne.
3. Skontroluj, či nie sú rohy zdvihnuté a či sú všetky otvory kruhové.
4. Vyskúšaj M3 skrutku postupne v spodnom rade od 3,2 mm po 3,8 mm.
5. Vyber najmenší otvor, cez ktorý M3 skrutka prejde rukou bez rezania závitu a bez násilia. Nemá sa však výrazne kývať do strán.
6. Heat-set vložku zatláčaj spájkovačkou kolmo a pomaly do horného radu. Začni najväčšou kapsou 4,8 mm a pokračuj k menším iba podľa potreby.
7. Vložku nezatláčaj až cez spodok. Horná hrana má po vychladnutí zostať zarovno s povrchom.
8. Po úplnom vychladnutí zaskrutkuj M3 skrutku a jemne over, či sa vložka nepretáča ani nevyťahuje.

Pri práci so spájkovačkou vetraj a nedotýkaj sa horúcej vložky. Ak musíš použiť veľkú silu alebo plast začne praskať, pokus zastav a použi väčšiu kapsu.

## Čo poslať späť

Pošli:

- fotografiu dielu zhora,
- fotografiu osadenej heat-set vložky zboku alebo šikmo,
- značku a typ PETG,
- teplotu trysky a podložky,
- číslo najlepšieho stĺpca pre heat-set vložku,
- číslo najlepšieho stĺpca pre M3 skrutku,
- informáciu, či sa vložka pri dotiahnutí pretáča.

Podľa výsledku sa nastavia všetky ďalšie diely projektu 737-800 Captain MIP.

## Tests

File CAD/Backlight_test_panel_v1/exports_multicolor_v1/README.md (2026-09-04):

# CAL-004 multicolor exports

The black face and each white legend STL share the same origin. Import them
as parts of one multicolor object, never auto-arrange the parts independently.

- Variant A uses the 1.0 mm legend export.
- Variant B uses the 0.4 mm legend export.
- The light base is printed once and reused for both optical tests.

See the matching `Ready-to-Print/Backlight-Multicolor-AB-CAL-004` instructions.

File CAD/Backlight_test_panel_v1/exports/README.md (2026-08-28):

# Backlight test panel v1

Opravená revízia v1.1 je uvoľnená v `Ready-to-Print/Backlight-Test-v1` spolu s tlačovým návodom. Všetky tri STL majú po oprave presne jeden spojený shell. Pôvodná v1 s voľnými stredmi písmen je archivovaná v `obsolete_v1` a nesmie sa tlačiť.

- `737-MIP-CAL-002_backlight-base_v1.1.stl`
- `737-MIP-CAL-002A_backlight-face_v1.1.stl`
- `737-MIP-CAL-002B_backlight-diffuser_v1.1.stl`

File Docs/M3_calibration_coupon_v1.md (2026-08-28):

# M3 kalibračný diel v1

Malý skúšobný diel určí správny priemer otvorov na konkrétnej tlačiarni, materiáli a profile 5s3a. Výsledok sa následne prenesie do všetkých veľkých nosných dielov.

## Obsah testu

Pri pohľade zhora sú štyri stĺpce zľava doprava:

| Stĺpec | Heat-set kapsa HS | Priechodzí otvor M3 |
|---:|---:|---:|
| 1 | 4,2 mm | 3,2 mm |
| 2 | 4,4 mm | 3,4 mm |
| 3 | 4,6 mm | 3,6 mm |
| 4 | 4,8 mm | 3,8 mm |

Horný rad označený `HS` má 4,2 mm hlboké slepé kapsy s 3,0 mm pilotným otvorom. Spodný rad `M3` sú priechodzie otvory.

## Tlač

- 1 kus, mierka 100 %.
- Rovnaký materiál, tryska a profil, aké sa použijú na carrier; odporúčanie PETG.
- Tryska 0,4 mm, vrstva 0,20 mm, 4 steny, 5 horných/spodných vrstiev.
- Položiť veľkou rovnou plochou na podložku, bez podpier.
- Rozmer dielu: 84 × 46 × 6 mm.

## Vyhodnotenie

1. Heat-set vložka má pri zahrievaní vojsť kolmo, bez praskania steny a po vychladnutí sa nesmie pretáčať ani vytiahnuť rukou.
2. M3 skrutka má cez zvolený priechodzí otvor prejsť rukou bez rezania závitu, ale bez zbytočne veľkej bočnej vôle.
3. Zapíšte zvolený stĺpec a materiál do tabuľky nižšie.

| Parameter | Výsledok |
|---|---|
| Tlačiareň | Anycubic Kobra X |
| Materiál/značka |  |
| Teplota trysky/podložky |  |
| Zvolená HS kapsa |  |
| Zvolený M3 otvor |  |
| Poznámka |  |

## Výsledok 5s3a – 2026-08-28

- Anycubic PETG sivý, tryska 230 °C, podložka 75 °C, flow 0,96, vrstva 0,20 mm.
- Rozmer 83,82 × 45,85 mm oproti 84 × 46 mm: rovnomerné zmrštenie približne 0,25 %.
- Najlepší M3 priechodzí otvor: **3,2 mm**.
- Heat-set kapsy neboli testované, pretože vložky ešte nie sú zakúpené.

Parameter `m3_clearance` je v nových revíziách nastavený na 3,2 mm pre tento materiál a profil. Pri zmene materiálu alebo flow sa test opakuje.

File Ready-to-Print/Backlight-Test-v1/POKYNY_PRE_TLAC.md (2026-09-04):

# Backlight test panel v1 – pokyny pre tlač

> **SUPERSEDED / DO NOT PRINT:** túto verziu nahradil multicolor A/B test
> `Backlight-Multicolor-AB-CAL-004`. Pôvodná face vrstva má voľné ostrovčeky.

## Diely

Vytlačiť po jednom kuse:

- `737-MIP-CAL-002_backlight-base_v1.1.stl`
- `737-MIP-CAL-002A_backlight-face_v1.1.stl`
- `737-MIP-CAL-002B_backlight-diffuser_v1.1.stl`

## Materiál a farby

- Základňa: biely PETG.
- Predná face vrstva: čierny PETG.
- Difúzor: biely PETG, hrúbka 0,4 mm (2 vrstvy pri 0,20 mm). Ak je k dispozícii natural/translucent PETG, možno vytlačiť aj druhý kus na porovnanie.
- Diely zatiaľ nestriekať. Testujeme priepustnosť svetla priamo cez materiál.

## Nastavenie

- Tryska 0,4 mm.
- Vrstva 0,20 mm; pre čiernu face vrstvu možno použiť 0,16 mm pre čistejšie písmo.
- 4 steny.
- 100 % výplň pre face a difúzor.
- 25 % gyroid pre základňu.
- 5 horných a spodných vrstiev.
- Bez podpier.
- Mierka presne 100 %.
- Každý diel položiť najväčšou rovnou plochou na podložku.

## Zostavenie testu

1. Odstrániť iba voľné vlákna; písmo nevŕtať ani nezväčšovať.
2. Do spredu otvoreného kanála základne vložiť dva rovné kusy 12 V bieleho COB pásika, šírka 5 mm, približne 90 mm na každej dlhej strane.
3. Difúzor položiť na svetlú základňu priamo nad LED kanál a navrch položiť čiernu face vrstvu. Poradie zozadu dopredu je: základňa → LED → 0,4 mm difúzor → čierna face vrstva.
4. Zarovnať štyri rohové M3 otvory. Na prvý test možno vrstvy spojiť páskou alebo štyrmi M3 skrutkami a maticami.
5. LED nepripájať priamo na Arduino pin. Použiť 12 V zdroj s kapacitou aspoň 0,5 A.
6. COB pásik neohýbať do strán. Rohy vynechať a dva úseky prepojiť vodičmi.
7. Testovať v dennom svetle aj v tme a odfotiť panel spredu.

## Čo vyhodnotiť

- či sú `PANEL`, `DIM`, `DUAL`, `TEST` a symbol rovnomerne presvietené,
- či čierna vrstva neprepúšťa svetlo mimo znakov,
- či vidno jednotlivé body LED,
- ktorý difúzor dáva lepší výsledok,
- či treba hlbší LED kanál alebo väčší odstup difúzora.

Otvor pri nápise `DUAL` je iba technologický placeholder. Dual-concentric encoder sa doň zatiaľ nemontuje.

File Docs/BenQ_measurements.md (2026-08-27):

# BenQ 18,5\" – merací protokol

Cradle sa nebude modelovať, kým nebudú vyplnené všetky kritické rozmery konkrétneho kusu.

| Rozmer | Hodnota (mm) | Poznámka |
|---|---:|---|
| Celková šírka monitora | 445 | bez stojana |
| Celková výška monitora | 266 | bez stojana |
| Maximálna hrúbka | 60 | bez stojana |
| Šírka aktívnej LCD plochy | 410 | iba svietiaca plocha |
| Výška aktívnej LCD plochy | 232 | iba svietiaca plocha |
| Ľavý okraj → aktívna plocha | 18 |  |
| Horný okraj → aktívna plocha | 18 |  |
| VESA horizontálny raster | 100 | stred–stred |
| VESA vertikálny raster | 100 | stred–stred |
| VESA stred od ľavého okraja | približne 220 | odvodené z ľavej hornej diery 170 mm |
| VESA stred od horného okraja | približne 130 | odvodené z ľavej hornej diery 80 mm |
| Závit VESA |  | napr. M4 |
| Maximálna bezpečná hĺbka skrutky |  | bez hrúbky držiaka |

Odfoť aj zadnú stranu, konektory a smer, ktorým musia vystupovať káble. Monitor netreba rozoberať.

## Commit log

2026-08-27 Add parametric PFD and ND carrier v1
    [737-MIP-003A_joiner-v1.stl, 737-MIP-003B_top-interface-v1.stl, 737-MIP-003_PFD-carrier_v1.stl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]
2026-08-27 Add ready-to-print M3 calibration coupon
    [737-MIP-CAL-001_M3-calibration-coupon_v1.stl, 737_MIP_M3_calibration_coupon_v1.scad, BOM.csv]
2026-08-27 Add PETG print instructions for 5s3a
2026-08-27 Finalize measured BenQ VESA cradle and carrier v1
    [737-MIP-003_PFD-carrier_v1.stl, 737-MIP-004_ND-carrier_v1.stl, 737-MIP-005A_rear-wing_v1.stl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]
2026-08-28 Add backlit DU bezel and dual encoder prototypes
    [737-MIP-001A_DU-bezel-dark-face_v3.stl, 737-MIP-001B_DU-bezel-diffuser_v3.stl, 737-MIP-001_DU-bezel-light-base_v3.stl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]
2026-08-28 docs: pridať výsledky CAL-001 a pripomienky k backlight testu a BenQ cradle
    CAL-001 vytlačený na Anycubic PETG sivý, 230/75 °C, flow 0,96.
    Zmrštenie −0,21 % / −0,33 %, M3 priechodzí otvor najlepší stĺpec 1 (3,2 mm).
    Heat-set rad netestovaný, vložky zatiaľ nie sú k dispozícii.
    Nálezy pred tlačou Backlight-Test-v1:
    - face vrstva má 5 voľných ostrovčekov (vnútra písmen P, A, D) — blokujúce
    - pokyny a CAD si protirečia v poradí vrstiev difúzora
    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
2026-08-28 Apply 5s3a calibration and fix backlight test v1.1
    [737-MIP-001A_DU-bezel-dark-face_v3.stl, 737-MIP-001B_DU-bezel-diffuser_v3.stl, 737-MIP-001_DU-bezel-light-base_v3.stl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]
2026-08-28 Add centered PFD ND fascia and alignment fit check
    [737-MIP-003_PFD-carrier_v1.stl, 737-MIP-004_ND-carrier_v1.stl, 737-MIP-006J_center-seam-joiner_v1.stl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]
2026-08-31 docs: výsledok CAL-003 fit-check a tri nálezy v CAD
    Všetky akceptačné kritériá splnené:
    - medzera medzi bezelmi 6,60 (cieľ 6,6 ±0,2)
    - viditeľný otvor 39,99 (cieľ 40,1 ±0,3)
    - stupeň v spoji fascie 0,01 (max 0,2)
    Chyby v CAD, ktoré znemožnili dva kroky montáže:
    - fascia_center má jazyk v rovine nôh, nedá sa zasunúť do medzery
    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
2026-09-03 docs: stratégia výroby panelov — Forex skriňa, tlačené multicolor popisy
    Rozhodnutia z 2026-09-03:
    - skriňa a rámy CNC z Forexu, predné panely s popismi sa tlačia
    - popisy multicolor namiesto prierezu cez čiernu dosku, stencil font sa ruší
    - zostávame pri parametrickom OpenSCAD, cudzie STL sa nekupujú
    Multicolor zároveň ruší blokujúcu chybu s voľnými ostrovčekmi vo face
    vrstve — pri dvoch exportoch zostane všetko spojené a font je voľný.
    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
2026-09-04 Fix CAL-003 fit and add multicolor backlight test
    [737-MIP-CAL-003B_assembly-preview_v1.1.3mf, 737-MIP-CAL-003B_fascia-center_v1.1.stl, 737-MIP-CAL-003B_fascia-seam-joiner_v1.1.stl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]
